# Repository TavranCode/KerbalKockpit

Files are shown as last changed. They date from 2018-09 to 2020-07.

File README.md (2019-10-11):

# KerbalKockpit
A custom control panel for Kerbal Space Program. Heavily cribbed from PeteWasEre

This repository is a place for me to keep and share my code, designs and data for my custom KSP Control Panel.

The contents are:

1. Arduino Code - The modules that run on the Arduino Duemilanove
2. Documentation - Doesn't exist yet!
3. Enclosure Design - The printed graphics used on the panels. Designed to print to a Glowforge
4. PCB design - what it says on the tin.
5. Python Code - The python module that runs at the PC end of the link

If it helps you then please use it. Better yet, consult the original.

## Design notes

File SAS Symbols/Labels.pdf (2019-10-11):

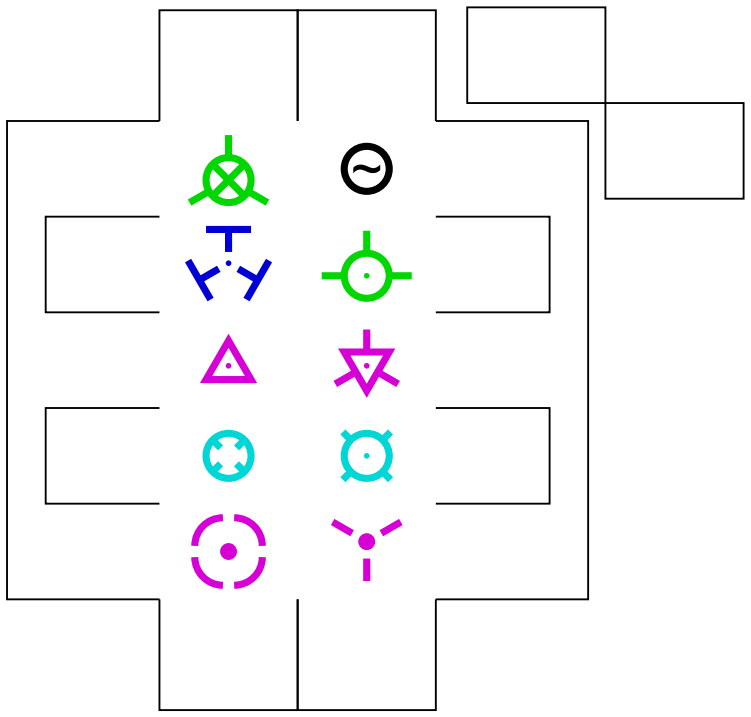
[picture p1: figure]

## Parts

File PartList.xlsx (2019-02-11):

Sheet: Sheet1
Row Labels | Count of Panel
2 axis joystick | 1
3 axis joystick | 1
3axis joystick w/button | 1
cover toggle | 2
large button | 3
led | 16
led button | 10
linpot | 1
momentary | 16
rocker | 3
rotary | 5
toggle | 5
(blank) | 1
Grand Total | 65

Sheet: Control List
Panel | in/out | Function | switch type | plotted | component | Digital Pins | PWM Pins | Analog Pins | Muxed? | Purchased? |  | In sketch | In panel svg
Attitude Control | in | SAS shutoff | large button | X | 1 | 1 | 0 | 0 | 0 | X |  | X
Attitude Control | in | SAS stability | led button | X | 1 | 1 | 0 | 0 | 0 | X |  | X
Attitude Control | in | SAS maneuver | led button | X | 1 | 1 | 0 | 0 | 0 | X |  | X
Attitude Control | in | SAS prograde | led button | X | 1 | 1 | 0 | 0 | 0 | X |  | X
Attitude Control | in | SAS retrograde | led button | X | 1 | 1 | 0 | 0 | 0 | X |  | X
Attitude Control | in | SAS normal | led button | X | 1 | 1 | 0 | 0 | 0 | X |  | X
Attitude Control | in | SAS anti-normal | led button | X | 1 | 1 | 0 | 0 | 0 | X |  | X
Attitude Control | in | SAS radial | led button | X | 1 | 1 | 0 | 0 | 0 | X |  | X
Attitude Control | in | SAS antiradial | led button | X | 1 | 1 | 0 | 0 | 0 | X |  | X
Attitude Control | in | SAS target | led button | X | 1 | 1 | 0 | 0 | 0 | X |  | X
Attitude Control | in | SAS anti-target | led button | X | 1 | 1 | 0 | 0 | 0 | X |  | X
Attitude Control | in | Attitude Joystick | 3axis joystick w/button | X | 2 | 1 | 0 | 3 | 0 | X |  | X
Attitude Control | out | SAS stability lamp | led | X |  | 1 | 0 | 0 | 1 | X |  | X
Attitude Control | out | SAS maneuver lamp | led | X |  | 1 | 0 | 0 | 1 | X |  | X
Attitude Control | out | SAS prograde lamp | led | X |  | 1 | 0 | 0 | 1 | X |  | X
Attitude Control | out | SAS retrograde lamp | led | X |  | 1 | 0 | 0 | 1 | X |  | X
Attitude Control | out | SAS normal lamp | led | X |  | 1 | 0 | 0 | 1 | X |  | X
Attitude Control | out | SAS anti-normal lamp | led | X |  | 1 | 0 | 0 | 1 | X |  | X
Attitude Control | out | SAS radial lamp | led | X |  | 1 | 0 | 0 | 1 | X |  | X
Attitude Control | out | SAS antiradial lamp | led | X |  | 1 | 0 | 0 | 1 | X |  | X
Attitude Control | out | SAS target | led | X |  | 1 | 0 | 0 | 1 | X |  | X
Attitude Control | out | SAS anti-target | led | X |  | 1 | 0 | 0 | 1 | X |  | X
 |  | SAS override |  |  |  |  |  |  |  |  | 19mm red push switch | X
System Control | in | Power |  |  |  | 0 | 0 | 0 | 0 |  |  | X
System Control | in | Reset | key switch |  |  | 0 | 0 | 0 | 0 | X |  | X
System Control | out | Overflow | led | X |  | 1 | 0 | 0 | 1 |  | color change led | X
System Control | out | Power lamp | led | X |  | 1 | 0 | 0 | 1 |  | color change led | X
System Control | out | Error lamp | led | X |  | 1 | 0 | 0 | 1 |  | " | X
Game Control | in | timewarp | rocker | X |  | 2 |  |  |  |  |  | X
Game Control |  | physwarp | rocker | X |  | 2 |  |  |  |  |  | X
Game Control |  | timeoveride | toggle | X |  | 1 |  |  |  |  | 19mm yellow button | X
Game Control |  | quicksave | momentary | X |  | 1 |  |  |  |  | 16mm black button | X
Game Control |  | quickload | momentary | X |  | 1 |  |  |  |  | 16mm black button | X
Game Control |  | vessel switch | rocker | X |  | 2 |  |  |  |  |  | X
Game Control |  | map | momentary | X |  | 1 |  |  |  |  | 16mm black button | X
Game Control |  | reset view | momentary | X |  | 1 |  |  |  |  | 16mm black button | X
Game Control |  | map target toggle | rocker | X |  | 2 |  |  |  |  |  | X
System Control |  | light test |  |  |  | 0 | 0 | 0 | 0 |  |  | X
Action Groups |  | AG 1 | momentary | X |  | 1 |  |  |  |  | tactile switch | X
Action Groups |  | AG 2 | momentary | X |  | 1 |  |  |  |  | tactile switch | X
Action Groups |  | AG 3 | momentary | X |  | 1 |  |  |  |  | tactile switch | X
Action Groups |  | AG 4 | momentary | X |  | 1 |  |  |  |  | tactile switch | X
Action Groups |  | AG 5 | momentary | X |  | 1 |  |  |  |  | tactile switch | X
Action Groups |  | AG 6 | momentary | X |  | 1 |  |  |  |  | tactile switch | X
Action Groups |  | AG 7 | momentary | X |  | 1 |  |  |  |  | tactile switch | X
Action Groups |  | AG 8 | momentary | X |  | 1 |  |  |  |  | tactile switch | X
Action Groups |  | AG 9 | momentary | X |  | 1 |  |  |  |  | tactile switch | X
Action Groups |  | AG 10 | momentary | X |  | 1 |  |  |  |  | tactile switch | X
System Control |  | surface/orbit/target | rotary | X |  | 2 |  |  |  |  |  | X
System Control |  | Lights | toggle | X |  | 1 |  |  |  | toggle |  | X
System Control |  | Gear | toggle | X |  | 1 |  |  |  | toggle |  | X
System Control |  | Brake | toggle | X |  | 1 |  |  |  | toggle |  | X
System Control |  | Light indicator | led | X |  | 1 |  |  |  |  | 3mm led | X
System Control |  | Gear Indicator | led | X |  | 1 |  |  |  |  | 3mm led | X
System Control |  | Brake Indicator | led | X |  | 1 |  |  |  |  | 3mm led | X
Staging |  | Arm Stage | cover toggle |  |  |  |  |  | X | Shield Switch
Staging |  | Stage | large button | X |  | 1 |  |  |  | mushroom Switch | 22 mm green button
Staging |  | Arm Abort | cover toggle |  |  |  |  |  | X | Shield Switch
Staging |  | Abort | large button | X |  | 1 |  |  |  | Mushroom Switch | 22 mm red button
Translation Control |  | 3 axis joystick | 3 axis joystick | X |  |  |  | 3
Translation Control |  | RCS toggle | toggle | X |  | 1
Throttle Control |  | linpot | linpot |  |  |  |  | 1 |  | X
Throttle Control |  | scale switch | rotary |  |  | 0 |  | 0
camera control |  | mode | rotary | X |  | 5
camera control |  | joystick | 2 axis joystick | X
camera control |  | camera zoom | rocker | X |  | 2
output panel:
 |  | fuel level
 |  | elect level
 |  | misc level
 |  | fuel rate
 |  | elect rate
 |  | fuel rate
 |  | stage toggle
 |  | alt. meter
 |  | radio meter
 |  | vel
 |  | vert vel
 |  | hor vel

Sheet: Proto Parts List
Switches: |  |  | Price Per lot | Needed | Min Lot | Price | Measured diameter | Datasheet diameter | Other diameter/notes
1 | Illuminated rectangle button | https://www.ebay.com/itm/10x-DC-12V-Push-Button-Momentary-Self-Reset-Square-Switch-with-LED-Lighted-White-/382028963367 | $10.27 | 10 | 10 | $10.27 | 15.5 | 16
2 | mom-off-mom switch | https://www.aliexpress.com/item/12V-6-Pin-DPDT-Power-Window-Momentary-Rocker-Switch-AC-250V-10A-125V-15A-Switch/32707229587.html | $1.15 | 3 | 1 | $3.45 |  | 21x28.5
4 | 3 axis joystick | https://www.ebay.com/itm/4-Axis-Plastic-Joystick-Potentiometer-For-JH-D400X-R4-10K-4D-with-Button-Wire-/202458110615 | 14 | 1 | 1 | $14.00 |  |  | screws are a 32.5mm square. joy cutout is 35mm round
5 | 3mm led holder |  | 1.04 | 6 | 20 | $1.04 | 5.4 | 6
6 | 5mm led holder |  | 1.56 | 1 | 20 | $1.56 | 7.2 | 8
7 | tactile switch |  | 3.99 |  | 20 | $0.00 | 6.4 | 7
8 | 22mm push | https://www.aliexpress.com/item/16-19-22mm-high-head-flat-head-round-head-metal-self-reset-button-switch-screw-pin/32911160248.html | 4 | 2 | 1 | $8.00 | 21.5 | 22
 | 19mm pushbutton | https://www.aliexpress.com/item/16-19-22mm-high-head-flat-head-round-head-metal-self-reset-button-switch-screw-pin/32911160248.html | 2.64 | 2 | 1 | $5.28 |  | 19
 | 16mm pushbutton | https://www.aliexpress.com/item/16-19-22mm-high-head-flat-head-round-head-metal-self-reset-button-switch-screw-pin/32911160248.html | 1.73 | 4 | 1 | $6.92 |  | 16
9 | rotary pot |  | 0.94 | 2 | 5 | $0.94 | 6.4 | 7
10 | rotary selector switch |  | 7.05 | 5 | 10 | $7.05 | 8.5 | 9
11 | large linpot | vetco |  | 1 |  | #DIV/0! |  |  | 2 mm holes with 77.3 mm between 71mm slot X 2
12 | resource light array | vetco |  | 2 |  | #DIV/0! | 46X6.4
 | DPDT switch | vetco |  |  |  | #DIV/0!
 | SPST switch | vetco |  |  |  | #DIV/0!
 | SPDT switch | vetco |  |  |  | #DIV/0!
 | Slide joystick | https://www.aliexpress.com/item/Hight-quality-Replacement-Parts-Black-3D-Button-Analog-Joystick-for-Sony-for-PSP1000-PSP-1000-PSP/32821042445.html | 2.02 | 1 | 1 | $2.02 |  | NA
 | Key switch |  | 3.5 | 1 | 1 | $3.50 |  | 22
 | 2 axis joystick | https://www.aliexpress.com/item/Free-Ship-2pcs-Model-airplane-B10K-RC-Plane-with-confirm-button-joystick-rocker-3D-RC-helicopter/32672519305.html | 7.35 | 2 | 2 | $7.35 | 22
 | Shielded lit toggle | https://www.sparkfun.com/products/11310 | 2.95 | 2 | 1 | $5.90 |  | 12
 | Small linpot | https://www.sparkfun.com/products/11621 | 3.45 | 1 | 1 |  |  | NA
Other: |  |  |  |  |  | #DIV/0!
 | Heat Shrink |  | 2.49 |  |  | #DIV/0!
 | Standoffs |  | 4.25 |  |  | #DIV/0!
 | Hinges |  |  |  |  | #DIV/0!
 | Headers |  | 0.89 |  |  | #DIV/0!
 | Trim Pots |  | 0.75 | 4 | 20 | $0.75
 | Diodes |  | 0.7 |  | 100 | $0.00
 | ULN arrays |  | 0.94 |  | 10 | $0.00
 | Loose TRansistors |  | 1.06 |  | 20 | $0.00
 | LED strips |  | 2.19 |  |  | #DIV/0!
 | MCP chip |  | 1.21 | 8 |  | #DIV/0!
 | pot handle |  | 1.27 |  | 10 | $0.00
 | Stripboard | https://www.aliexpress.com/item/5-Pcs-6-5x14-5cm-Stripboard-Veroboard-Prototype-Printed-Circuit-Uncut-PCB-Platine-Single-Side-Circuit/32851727414.html | 2.58 |  | 5 | $0.00
 | 74HC4051 |  | 3.04 | 2 | 5 | $3.04
Tools/Other
 | Multimeter
 | Wire Stripper
 | Power Source

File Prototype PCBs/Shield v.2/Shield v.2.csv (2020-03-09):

Source: | C:\Users\Matt Peverill\Dropbox\KerbalKockpit\Prototype PCBs\Shield v.2\Shield v.2.sch
Date: | 2/13/2020 9:13
Tool: | Eeschema (5.1.5)-3
Component Count: | 175
Ref | Value | Footprint | Datasheet | Manufacturer | Vendor
A1 | Conn_01x15 | Connector_PinHeader_2.54mm:PinHeader_1x15_P2.54mm_Vertical | ~ |  | OWN
C1 | C | Capacitor_SMD:C_0603_1608Metric | ~ |  | Mouser
C2 | C | Capacitor_SMD:C_0603_1608Metric | ~ |  | Mouser
C3 | C | Capacitor_SMD:C_0603_1608Metric | ~ |  | Mouser
C4 | C | Capacitor_SMD:C_0603_1608Metric | ~ |  | Mouser
C5 | C | Capacitor_SMD:C_0603_1608Metric | ~ |  | Mouser
D1 | D | Diode_SMD:D_SOD-323 | ~
D2 | D | Diode_SMD:D_SOD-323 | ~
D3 | D | Diode_SMD:D_SOD-323 | ~
D4 | D | Diode_SMD:D_SOD-323 | ~
D5 | D | Diode_SMD:D_SOD-323 | ~
D6 | D | Diode_SMD:D_SOD-323 | ~
D7 | D | Diode_SMD:D_SOD-323 | ~
D8 | D | Diode_SMD:D_SOD-323 | ~
D9 | D | Diode_SMD:D_SOD-323 | ~
D10 | D | Diode_SMD:D_SOD-323 | ~
D11 | D | Diode_SMD:D_SOD-323 | ~
D12 | D | Diode_SMD:D_SOD-323 | ~
D13 | D | Diode_SMD:D_SOD-323 | ~
D14 | D | Diode_SMD:D_SOD-323 | ~
D15 | D | Diode_SMD:D_SOD-323 | ~
D16 | D | Diode_SMD:D_SOD-323 | ~
D17 | 1N4148 | Diode_SMD:D_SOD-323
D18 | 1N4148 | Diode_SMD:D_SOD-323
D19 | 1N4148 | Diode_SMD:D_SOD-323
D20 | 1N4148 | Diode_SMD:D_SOD-323
D21 | 1N4148 | Diode_SMD:D_SOD-323
D22 | 1N4148 | Diode_SMD:D_SOD-323
D23 | 1N4148 | Diode_SMD:D_SOD-323
D24 | 1N4148 | Diode_SMD:D_SOD-323
D25 | 1N4148 | Diode_SMD:D_SOD-323
D26 | 1N4148 | Diode_SMD:D_SOD-323
D27 | 1N4148 | Diode_SMD:D_SOD-323
D28 | 1N4148 | Diode_SMD:D_SOD-323
D29 | 1N4148 | Diode_SMD:D_SOD-323
D30 | 1N4148 | Diode_SMD:D_SOD-323
D31 | 1N4148 | Diode_SMD:D_SOD-323
D32 | 1N4148 | Diode_SMD:D_SOD-323
D33 | 1N4148 | Diode_SMD:D_SOD-323
D34 | 1N4148 | Diode_SMD:D_SOD-323
D35 | 1N4148 | Diode_SMD:D_SOD-323
D36 | 1N4148 | Diode_SMD:D_SOD-323
D37 | 1N4148 | Diode_SMD:D_SOD-323
D38 | 1N4148 | Diode_SMD:D_SOD-323
D39 | 1N4148 | Diode_SMD:D_SOD-323
D40 | 1N4148 | Diode_SMD:D_SOD-323
D41 | 1N4148 | Diode_SMD:D_SOD-323
D42 | 1N4148 | Diode_SMD:D_SOD-323
D43 | 1N4148 | Diode_SMD:D_SOD-323
D44 | 1N4148 | Diode_SMD:D_SOD-323
D45 | 1N4148 | Diode_SMD:D_SOD-323
D46 | 1N4148 | Diode_SMD:D_SOD-323
D47 | 1N4148 | Diode_SMD:D_SOD-323
D48 | 1N4148 | Diode_SMD:D_SOD-323
D49 | 1N4148 | Diode_SMD:D_SOD-323
D50 | 1N4148 | Diode_SMD:D_SOD-323
D51 | 1N4148 | Diode_SMD:D_SOD-323
D52 | 1N4148 | Diode_SMD:D_SOD-323
D53 | 1N4148 | Diode_SMD:D_SOD-323
D54 | 1N4148 | Diode_SMD:D_SOD-323
D55 | 1N4148 | Diode_SMD:D_SOD-323
D56 | 1N4148 | Diode_SMD:D_SOD-323
D57 | 1N4148 | Diode_SMD:D_SOD-323
D58 | 1N4148 | Diode_SMD:D_SOD-323
D59 | 1N4148 | Diode_SMD:D_SOD-323
D60 | 1N4148 | Diode_SMD:D_SOD-323
D61 | 1N4148 | Diode_SMD:D_SOD-323
D62 | 1N4148 | Diode_SMD:D_SOD-323
D63 | 1N4148 | Diode_SMD:D_SOD-323
D64 | 1N4148 | Diode_SMD:D_SOD-323
D65 | 1N4148 | Diode_SMD:D_SOD-323
D66 | 1N4148 | Diode_SMD:D_SOD-323
D67 | 1N4148 | Diode_SMD:D_SOD-323
D68 | 1N4148 | Diode_SMD:D_SOD-323
D69 | 1N4148 | Diode_SMD:D_SOD-323
D70 | 1N4148 | Diode_SMD:D_SOD-323
D71 | 1N4148 | Diode_SMD:D_SOD-323
D72 | 1N4148 | Diode_SMD:D_SOD-323
D73 | 1N4148 | Diode_SMD:D_SOD-323
D74 | 1N4148 | Diode_SMD:D_SOD-323
D75 | 1N4148 | Diode_SMD:D_SOD-323
D76 | 1N4148 | Diode_SMD:D_SOD-323
D77 | 1N4148 | Diode_SMD:D_SOD-323
D78 | 1N4148 | Diode_SMD:D_SOD-323
D79 | 1N4148 | Diode_SMD:D_SOD-323
D80 | 1N4148 | Diode_SMD:D_SOD-323
G1 | Conn_01x15 | Connector_PinHeader_2.54mm:PinHeader_1x15_P2.54mm_Vertical | ~ |  | Own
J1 | Conn_01x04 | Connector_PinHeader_2.54mm:PinHeader_1x04_P2.54mm_Vertical | ~ |  | Own
J2 | Conn_01x06 | Connector_PinHeader_2.54mm:PinHeader_1x06_P2.54mm_Vertical | ~ |  | Own
J3 | Conn_01x04 | Connector_PinHeader_2.54mm:PinHeader_1x04_P2.54mm_Vertical | ~ |  | Own
J4 | Conn_01x05 | Connector_PinHeader_2.54mm:PinHeader_1x05_P2.54mm_Vertical | ~ |  | Own
J5 | Motor | Connector_PinHeader_2.54mm:PinHeader_1x05_P2.54mm_Vertical | ~ |  | Own
J6 | Conn_01x03 | Connector_PinHeader_2.54mm:PinHeader_1x03_P2.54mm_Vertical | ~ |  | Own
J7 | Conn_01x07 | Connector_PinHeader_2.54mm:PinHeader_1x07_P2.54mm_Vertical | ~ |  | Own
J8 | Conn_01x04 | Connector_PinHeader_2.54mm:PinHeader_1x04_P2.54mm_Vertical | ~ |  | Own
J9 | Conn_Reset | Connector_PinHeader_2.54mm:PinHeader_1x02_P2.54mm_Vertical | ~ |  | Own
J10 | i2cA | Connector_PinHeader_2.54mm:PinHeader_2x04_P2.54mm_Vertical | ~ |  | Own
J11 | i2cB | Connector_PinHeader_2.54mm:PinHeader_2x04_P2.54mm_Vertical | ~ |  | Own
J14 | Conn_SysBut | Connector_PinHeader_2.54mm:PinHeader_1x04_P2.54mm_Vertical | ~ |  | Own
J15 | Conn_bLight | Connector_PinHeader_2.54mm:PinHeader_1x02_P2.54mm_Vertical | ~ |  | Own
J16 | Conn_SysLED | Connector_PinHeader_2.54mm:PinHeader_2x02_P2.54mm_Vertical | ~ |  | Own
J17 | LEDs_A | Connector_PinHeader_2.54mm:PinHeader_2x08_P2.54mm_Vertical | ~ |  | Own
J18 | LEDs_B | Connector_PinHeader_2.54mm:PinHeader_2x08_P2.54mm_Vertical | ~ |  | Own
J19B1 | Jumper_NO_Small | Connector_PinHeader_2.54mm:PinHeader_1x02_P2.54mm_Vertical | ~ |  | Own
J19C1 | Jumper_NO_Small | Connector_PinHeader_2.54mm:PinHeader_1x02_P2.54mm_Vertical | ~ |  | Own
J19C2 | Jumper_NO_Small | Connector_PinHeader_2.54mm:PinHeader_1x02_P2.54mm_Vertical | ~ |  | Own
J19D1 | Jumper_NO_Small | Connector_PinHeader_2.54mm:PinHeader_1x02_P2.54mm_Vertical | ~ |  | Own
J19F1 | Jumper_NO_Small | Connector_PinHeader_2.54mm:PinHeader_1x02_P2.54mm_Vertical | ~ |  | Own
J19F2 | Jumper_NO_Small | Connector_PinHeader_2.54mm:PinHeader_1x02_P2.54mm_Vertical | ~ |  | Own
J19G1 | Jumper_NO_Small | Connector_PinHeader_2.54mm:PinHeader_1x02_P2.54mm_Vertical | ~ |  | Own
J19H1 | Jumper_NO_Small | Connector_PinHeader_2.54mm:PinHeader_1x02_P2.54mm_Vertical | ~ |  | Own
J20 | JumpSwitch | Connector_PinHeader_2.54mm:PinHeader_2x08_P2.54mm_Vertical |  |  | Own
J21 | JumpSwitch | Connector_PinHeader_2.54mm:PinHeader_2x08_P2.54mm_Vertical |  |  | Own
J22 | JumpSwitch | Connector_PinHeader_2.54mm:PinHeader_2x08_P2.54mm_Vertical |  |  | Own
J23 | JumpSwitch | Connector_PinHeader_2.54mm:PinHeader_2x08_P2.54mm_Vertical |  |  | Own
J24 | JumpSwitch | Connector_PinHeader_2.54mm:PinHeader_2x08_P2.54mm_Vertical |  |  | Own
J25 | JumpSwitch | Connector_PinHeader_2.54mm:PinHeader_2x08_P2.54mm_Vertical |  |  | Own
J26A1 | Jumper_NO_Small | Connector_PinHeader_2.54mm:PinHeader_1x02_P2.54mm_Vertical | ~ |  | Own
J26B1 | Jumper_NO_Small | Connector_PinHeader_2.54mm:PinHeader_1x02_P2.54mm_Vertical | ~ |  | Own
J26C1 | Jumper_NO_Small | Connector_PinHeader_2.54mm:PinHeader_1x02_P2.54mm_Vertical | ~ |  | Own
J26D1 | Jumper_NO_Small | Connector_PinHeader_2.54mm:PinHeader_1x02_P2.54mm_Vertical | ~ |  | Own
J26E1 | Jumper_NO_Small | Connector_PinHeader_2.54mm:PinHeader_1x02_P2.54mm_Vertical | ~ |  | Own
J26F1 | Jumper_NO_Small | Connector_PinHeader_2.54mm:PinHeader_1x02_P2.54mm_Vertical | ~ |  | Own
J26G1 | Jumper_NO_Small | Connector_PinHeader_2.54mm:PinHeader_1x02_P2.54mm_Vertical | ~ |  | Own
J26H1 | Jumper_NO_Small | Connector_PinHeader_2.54mm:PinHeader_1x02_P2.54mm_Vertical | ~ |  | Own
Q1 | Q_NMOS_DIM | Package_TO_SOT_SMD:SOT-23 | ~ |  | Mouser
Q2 | Q_NMOS_DIM | Package_TO_SOT_SMD:SOT-23 | ~ |  | Mouser
R1 | R4.7k | Resistor_SMD:R_0603_1608Metric | ~ |  | Mouser
R2 | R4.7k | Resistor_SMD:R_0603_1608Metric | ~ |  | Mouser
R3 | R | Resistor_SMD:R_0603_1608Metric | ~ |  | Mouser
R4 | R | Resistor_SMD:R_0603_1608Metric | ~ |  | Mouser
R5 | R | Resistor_SMD:R_0603_1608Metric | ~ |  | Mouser
R6 | R | Resistor_SMD:R_0603_1608Metric | ~ |  | Mouser
R7 | R | Resistor_SMD:R_0603_1608Metric | ~ |  | Mouser
R8 | R | Resistor_SMD:R_0603_1608Metric | ~ |  | Mouser
R9 | R | Resistor_SMD:R_0603_1608Metric | ~ |  | Mouser
R10 | R | Resistor_SMD:R_0603_1608Metric | ~ |  | Mouser
R11 | R | Resistor_SMD:R_0603_1608Metric | ~ |  | Mouser
R12 | R | Resistor_SMD:R_0603_1608Metric | ~ |  | Mouser
R13 | R | Resistor_SMD:R_0603_1608Metric | ~ |  | Mouser
R14 | R | Resistor_SMD:R_0603_1608Metric | ~ |  | Mouser
R15 | R | Resistor_SMD:R_0603_1608Metric | ~ |  | Mouser
R16 | R | Resistor_SMD:R_0603_1608Metric | ~ |  | Mouser
R17 | R | Resistor_SMD:R_0603_1608Metric | ~ |  | Mouser
R18 | R | Resistor_SMD:R_0603_1608Metric | ~ |  | Mouser
R19 | R | Resistor_SMD:R_0603_1608Metric | ~ |  | Mouser
R20 | R | Resistor_SMD:R_0603_1608Metric | ~ |  | Mouser
R21 | R1k | Resistor_SMD:R_0603_1608Metric | ~ |  | Mouser
R22 | R1k | Resistor_SMD:R_0603_1608Metric | ~ |  | Mouser
R23 | R4.7k | Resistor_SMD:R_0603_1608Metric | ~ |  | Mouser
R24 | R4.7k | Resistor_SMD:R_0603_1608Metric | ~ |  | Mouser
R25 | R4.7k | Resistor_SMD:R_0603_1608Metric | ~ |  | Mouser
R26 | R4.7k | Resistor_SMD:R_0603_1608Metric | ~ |  | Mouser
R27 | R4.7k | Resistor_SMD:R_0603_1608Metric | ~ |  | Mouser
R28 | R4.7k | Resistor_SMD:R_0603_1608Metric | ~ |  | Mouser
R29 | R4.7k | Resistor_SMD:R_0603_1608Metric | ~ |  | Mouser
R30 | R4.7k | Resistor_SMD:R_0603_1608Metric | ~ |  | Mouser
R31 | R4.7k | Resistor_SMD:R_0603_1608Metric | ~ |  | Mouser
R32 | R4.7k | Resistor_SMD:R_0603_1608Metric | ~ |  | Mouser
SW1 | SW_Push | Kicad Parts:SW_PUSH-12mm_widepinholes |  |  |  | https://www.aliexpress.com/item/1649844130.html?spm=a2g0s.9042311.0.0.27424c4daOGlAI
SW2 | SW_Push | Kicad Parts:SW_PUSH-12mm_widepinholes
SW3 | SW_Push | Kicad Parts:SW_PUSH-12mm_widepinholes
SW4 | SW_Push | Kicad Parts:SW_PUSH-12mm_widepinholes
SW5 | SW_Push | Kicad Parts:SW_PUSH-12mm_widepinholes
SW6 | SW_Push | Kicad Parts:SW_PUSH-12mm_widepinholes
SW7 | SW_Push | Kicad Parts:SW_PUSH-12mm_widepinholes
SW8 | SW_Push | Kicad Parts:SW_PUSH-12mm_widepinholes
SW9 | SW_Push | Kicad Parts:SW_PUSH-12mm_widepinholes
SW10 | SW_Push | Kicad Parts:SW_PUSH-12mm_widepinholes
U1 | 74HC4051 | Package_SO:SSOP-16_3.9x4.9mm_P0.635mm | http://www.ti.com/lit/ds/symlink/cd74hc4051.pdf |  | Mouser
U2 | MCP23017_0x20_in | Package_SO:SSOP-28_5.3x10.2mm_P0.65mm | http://ww1.microchip.com/downloads/en/DeviceDoc/20001952C.pdf |  | Mouser
U3 | MCP23017_0x21_out | Package_SO:SSOP-28_5.3x10.2mm_P0.65mm | http://ww1.microchip.com/downloads/en/DeviceDoc/20001952C.pdf |  | Mouser
U4 | ULN2803A | Package_SO:SOIC-18W_7.5x11.6mm_P1.27mm | http://www.ti.com/lit/ds/symlink/uln2803a.pdf |  | Mouser
U5 | ULN2803A | Package_SO:SOIC-18W_7.5x11.6mm_P1.27mm | http://www.ti.com/lit/ds/symlink/uln2803a.pdf |  | Mouser
V1 | Conn_01x15 | Connector_PinHeader_2.54mm:PinHeader_1x15_P2.54mm_Vertical | ~ |  | OWN
 | MOUNTING HARDWARE | #
Shield - Stand-offs | 5/32" #2 standoff | 4 | https://www.mouser.com/ProductDetail/710-970050244
Shield - Panel Screws |  | 4 | https://www.boltdepot.com/Metric_machine_screws_Phillips_flat_head_Stainless_steel_18-8_(A-2)_2mm_x_0.4mm.aspx
Shield - Board Screws |  | 4 | https://www.boltdepot.com/Product-Details.aspx?product=6844
Shield - Washers |  | 0 | https://www.boltdepot.com/Product-Details.aspx?product=7364
Button Panel - Stand-offs | 5/32" #2 standoff | 3
Button Panel - Stand-offs
Button Panel - Panel Screws
Button Panel - Board Screws
Button Panel - Washers
PSP Analog Screws |  | 4 | https://www.metricscrews.us/index.php?main_page=product_info&products_id=1347&zenid=k8udfabh2ck7jem5e6mimm35a2
Adhesive Cable Clips |  |  | https://www.amazon.com/gp/product/B072XJT436/ref=crt_ewc_img_dp_2?ie=UTF8&psc=1&smid=AWAGKS3NENVQT
Paper Clip |  |  | https://www.amazon.com/gp/product/B001F6TDEW/ref=crt_ewc_title_dp_1?ie=UTF8&psc=1&smid=ATVPDKIKX0DER
#4Screw for Paper Clip |  | 1 w/nut and washer

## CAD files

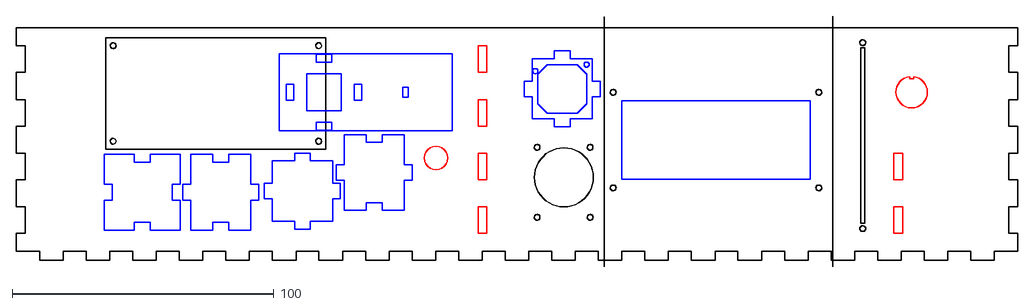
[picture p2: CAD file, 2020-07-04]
Enclosure Design/Cuttest 2-16-2020.dxf
382.2 x 95.7

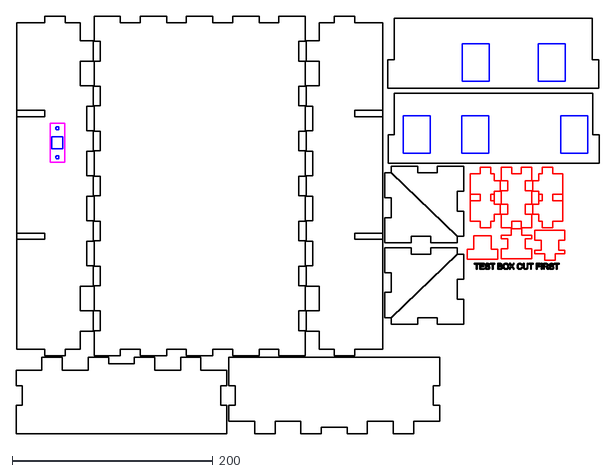
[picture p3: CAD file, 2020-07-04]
Enclosure Design/Panel-v3/Enclosure.dxf
581.1 x 416.2

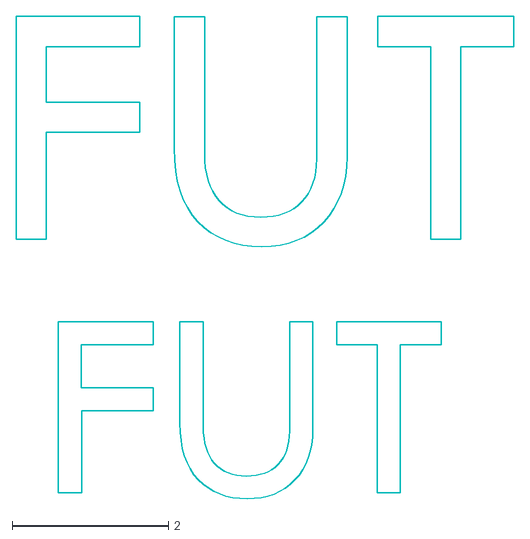
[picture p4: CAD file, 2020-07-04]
Enclosure Design/Panel-v3/Test and Development Files/Text.dxf
6.38 x 6.18

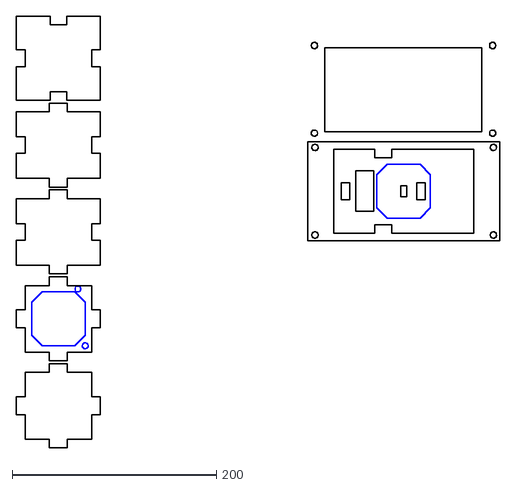
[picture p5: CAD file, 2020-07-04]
Enclosure Design/Cuttest 2-16-2020b.dxf
472.8 x 422.2

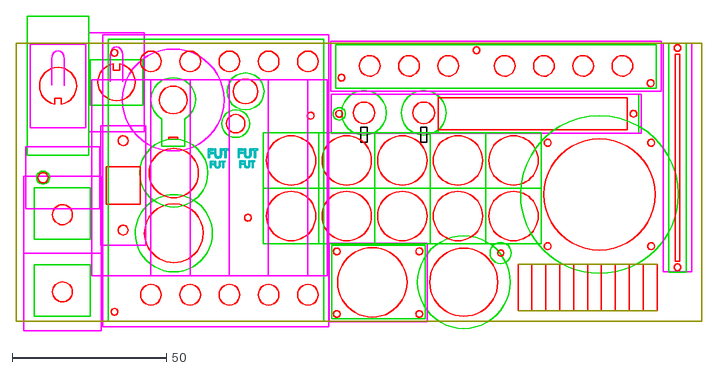
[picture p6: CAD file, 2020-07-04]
Enclosure Design/Panel-v3/Test and Development Files/AcrylicCutTest1.dxf
222.0 x 101.7

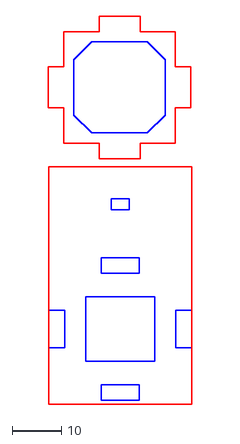
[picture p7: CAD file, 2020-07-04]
Enclosure Design/Panel-v3/Translation Control Parts 2.dxf
29.1 x 78.9

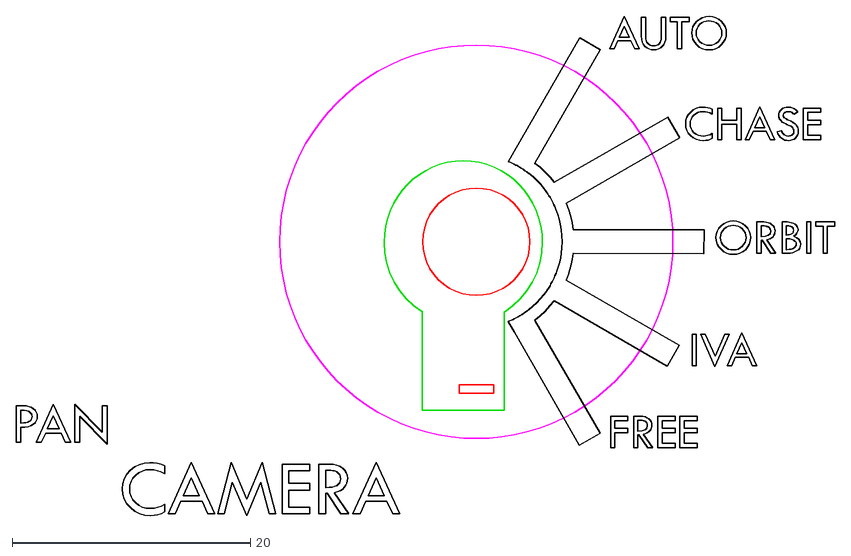
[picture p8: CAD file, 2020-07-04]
Enclosure Design/Panel-v3/Test and Development Files/finalengravetest.dxf
68.7 x 41.9

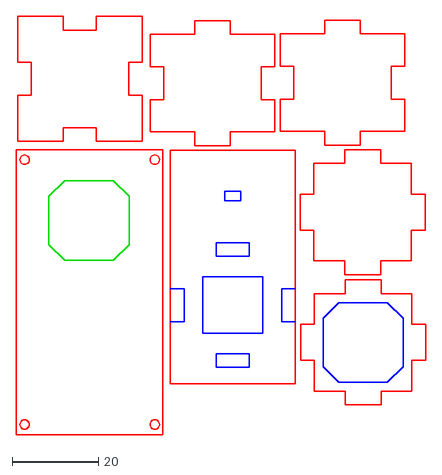
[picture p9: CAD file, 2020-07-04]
Enclosure Design/Panel-v3/Translation Control Parts.dxf
95.1 x 97.2

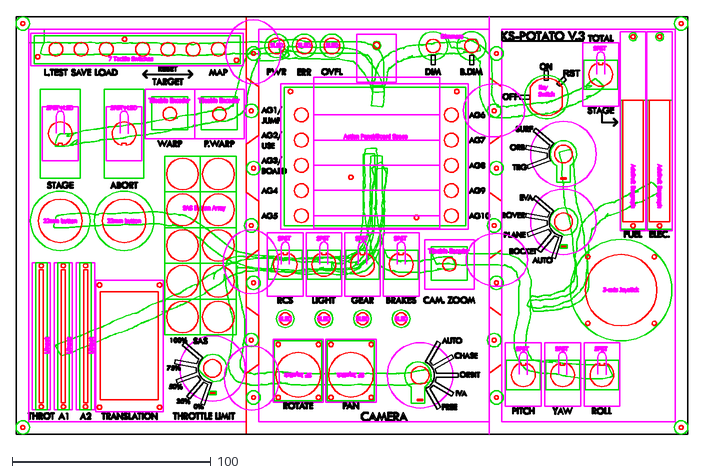
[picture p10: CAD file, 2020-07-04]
Enclosure Design/Panel-v3/Panel-v3.dxf
338.5 x 210.6

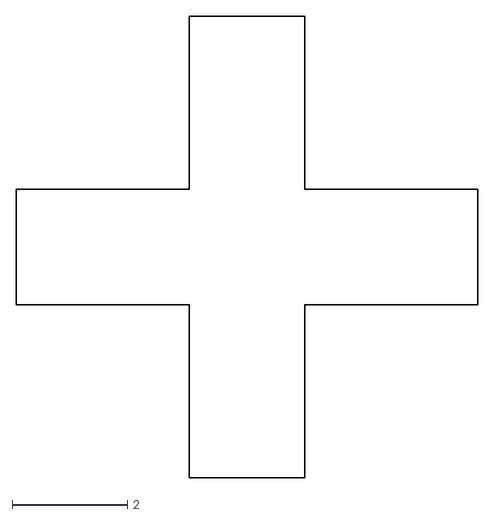
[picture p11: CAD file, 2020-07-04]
Enclosure Design/Panel-v3/Test and Development Files/2mmcross.dxf
8.00 x 8.00

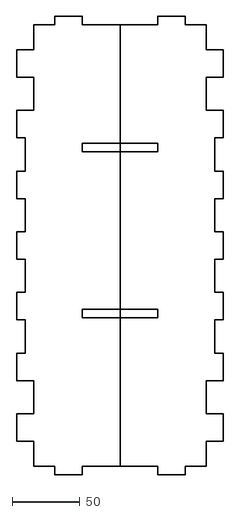
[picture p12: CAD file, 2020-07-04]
Enclosure Design/Panel-v3/NewSides.dxf
152.4 x 338.5

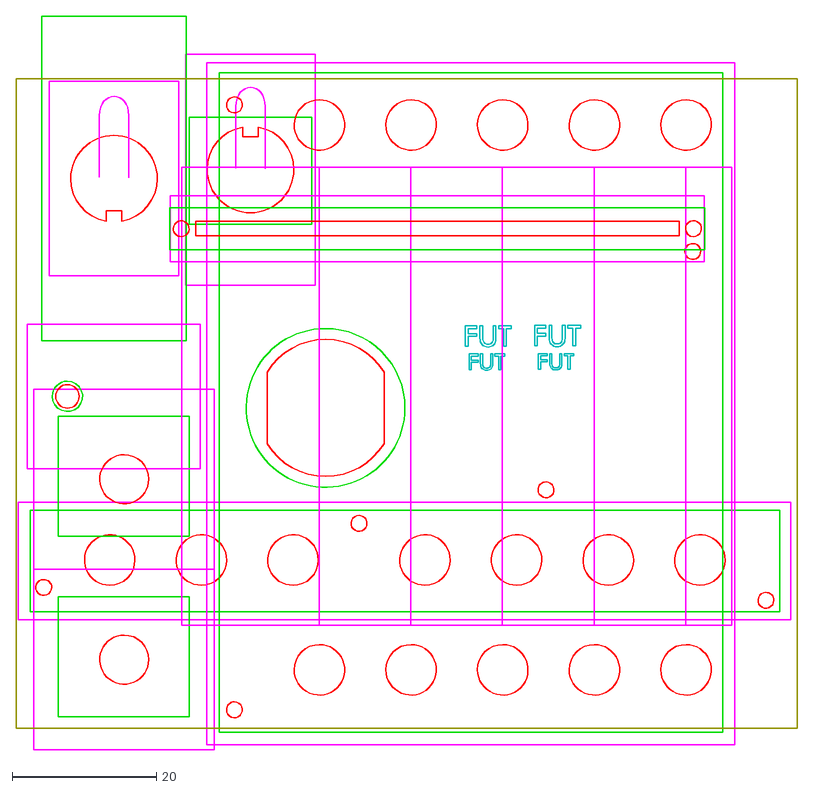
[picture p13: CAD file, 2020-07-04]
Enclosure Design/Panel-v3/Test and Development Files/AcrylicCutTest2.dxf
108.2 x 101.7

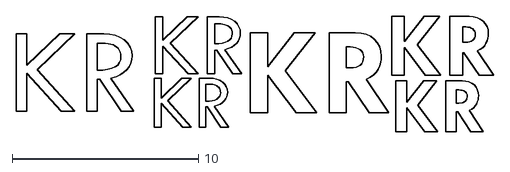
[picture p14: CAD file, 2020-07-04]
Enclosure Design/Panel-v3/Test and Development Files/Futura Sample.dxf
25.6 x 6.18

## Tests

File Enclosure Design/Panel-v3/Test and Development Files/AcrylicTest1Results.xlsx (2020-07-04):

 | Tested | Corrections | Re-design | Test
Rotary | X
Brain Board | X | Increase Button width to 7mm | X | X
Button Board | X | " | X | X
Linpot | X | Slot width > 1.8-2mm | X | X
Ada barplot | X
encoder | X | hole too small - spacing is perfect. Should be 6.5mm | X | X
switch |  | counter-rotation is too long | X | just a little looser
shield switch |  | " | X | "
5mm led
3mm led
usb port | X
22mm button | X
18mm button | X
KeySwitch | X | Add sides and make hole bigger | X
Dimmers | x
Big Joystick
SF Joystick | X
SAS array | X
Rotary Switch | X
Notes Sheet | X

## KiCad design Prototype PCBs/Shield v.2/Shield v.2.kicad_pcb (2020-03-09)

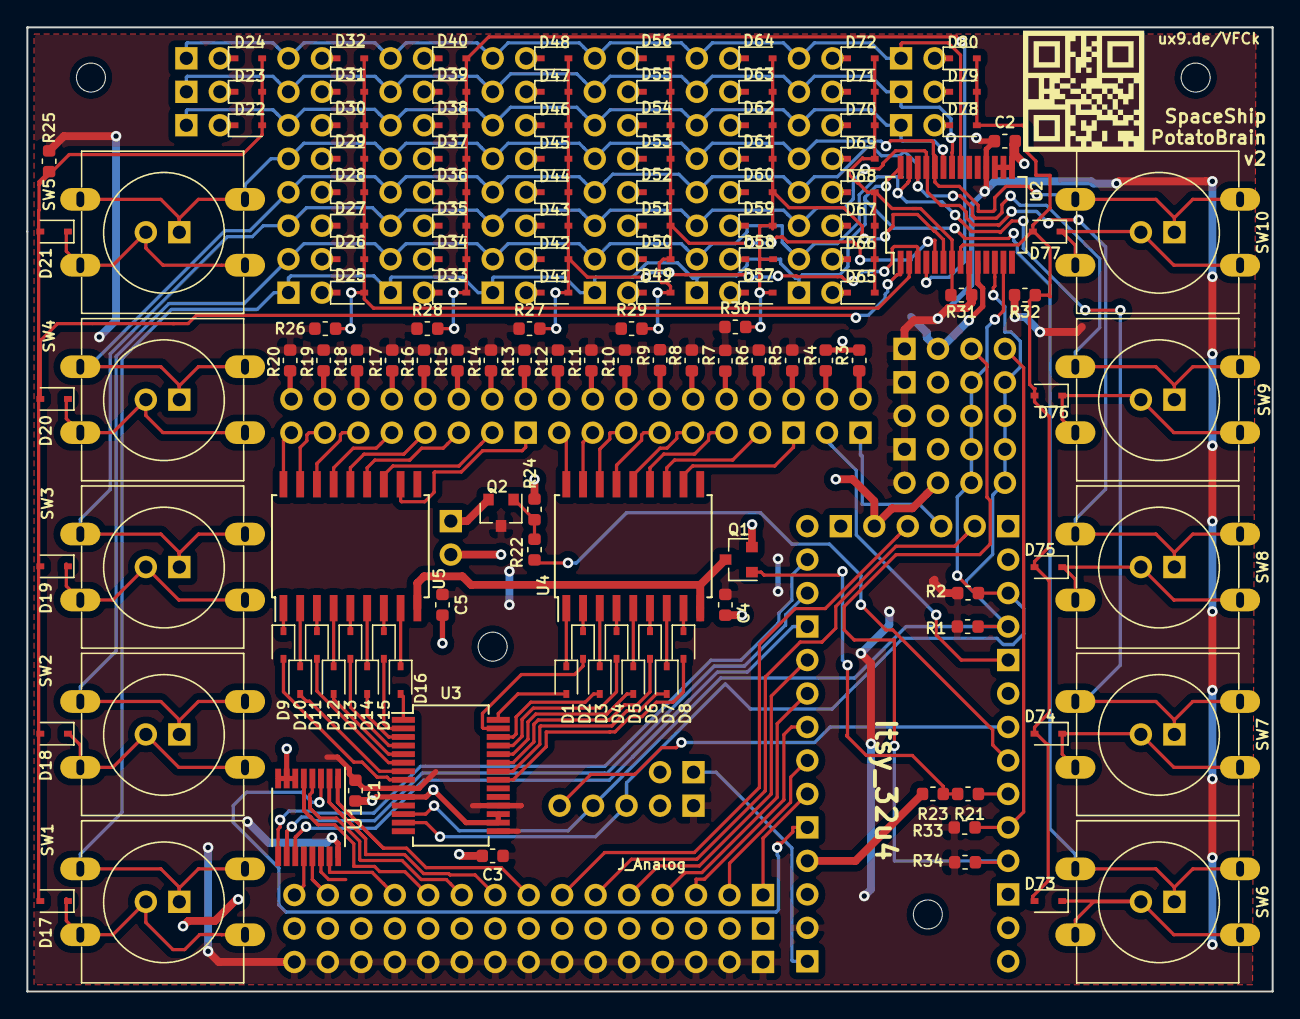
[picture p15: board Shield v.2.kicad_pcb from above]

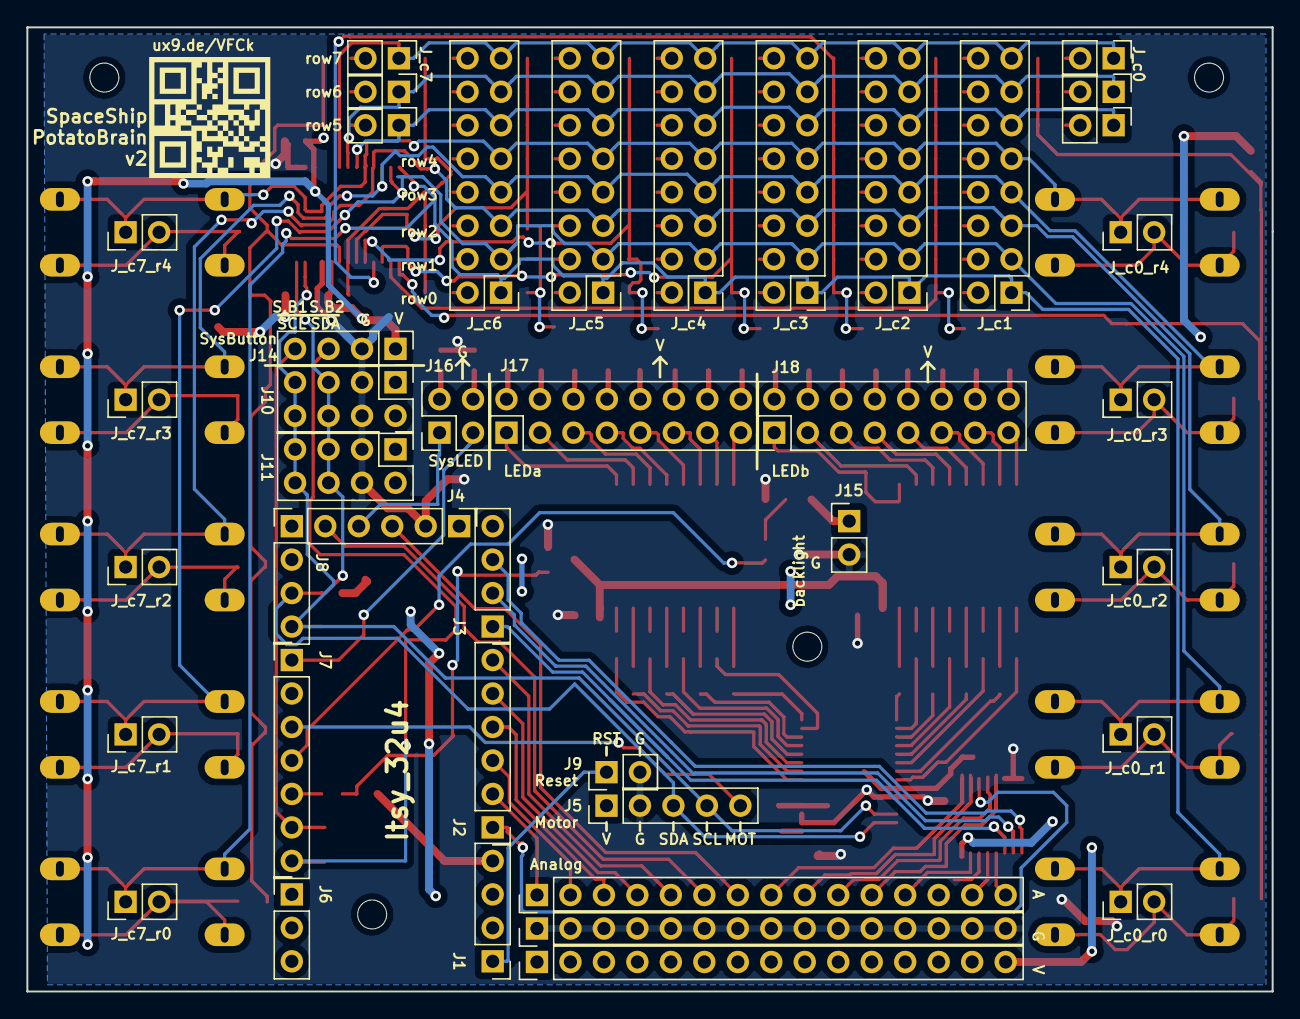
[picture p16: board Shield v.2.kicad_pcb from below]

Board: 2 copper layers, 94.5 x 73.2 mm, 183 parts (42 on the bottom side), 181 nets.

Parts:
A: Conn_01x15; PinHeader_1x15_P2.54mm_Vertical
C1, C2, C3, C4, C5: C; C_0603_1608Metric
D1, D2, D3, D4, D5, D6, D7, D8, D9, D10, D11, D12, D13, D14, D15, D16: D; D_SOD-323
D17, D18, D19, D20, D21, D22, D23, D24, D25, D26, D27, D28, D29, D30, D31, D32, D33, D34, D35, D36, D37, D38, D39, D40, D41, D42, D43, D44, D45, D46, D47, D48, D49, D50, D51, D52, D53, D54, D55, D56, D57, D58, D59, D60, D61, D62, D63, D64, D65, D66, D67, D68, D69, D70, D71, D72, D73, D74, D75, D76, D77, D78, D79, D80: 1N4148; D_SOD-323
G: Conn_01x15; PinHeader_1x15_P2.54mm_Vertical
J1, J3, J8: Conn_01x04; PinHeader_1x04_P2.54mm_Vertical
J2: Conn_01x06; PinHeader_1x06_P2.54mm_Vertical
J4: Conn_01x05; PinHeader_1x05_P2.54mm_Vertical
J5: Motor; PinHeader_1x05_P2.54mm_Vertical
J6: Conn_01x03; PinHeader_1x03_P2.54mm_Vertical
J7: Conn_01x07; PinHeader_1x07_P2.54mm_Vertical
J9: Conn_Reset; PinHeader_1x02_P2.54mm_Vertical
J10: i2cA; PinHeader_2x04_P2.54mm_Vertical
J11: i2cB; PinHeader_2x04_P2.54mm_Vertical
J14: Conn_SysBut; PinHeader_1x04_P2.54mm_Vertical
J15: Conn_bLight; PinHeader_1x02_P2.54mm_Vertical
J16: Conn_SysLED; PinHeader_2x02_P2.54mm_Vertical
J17: LEDs_A; PinHeader_2x08_P2.54mm_Vertical
J18: LEDs_B; PinHeader_2x08_P2.54mm_Vertical
J19F2, J19G1, J26F1, J26G1: Jumper_NO_Small; PinHeader_1x02_P2.54mm_Vertical
J_c0, J_c0_r0, J_c0_r1, J_c0_r2, J_c0_r3, J_c0_r4, J_c7, J_c7_r0, J_c7_r1, J_c7_r2, J_c7_r3, J_c7_r4: Jumper_NO_Small; PinHeader_1x02_P2.54mm_Vertical
J_c1, J_c2, J_c3, J_c4, J_c5, J_c6: JumpSwitch; PinHeader_2x08_P2.54mm_Vertical
Mount1, Mount2, Mount3, Mount4: MountingHole_2.2mm_M2
Q1, Q2: Q_NMOS_DIM; SOT-23
QR*****: ux9.de/VFCk; ux9.de_VFCk
QR*****#2: ux9.de/VFCk; ux9.de_VFCk
R1, R2, R23, R24, R25, R26, R27, R28, R29, R30, R31, R32, R33, R34: R4.7k; R_0603_1608Metric
R3, R4, R5, R6, R7, R8, R9, R10, R11, R12, R13, R14, R15, R16, R17, R18, R19, R20: R; R_0603_1608Metric
R21, R22: R1k; R_0603_1608Metric
SW1, SW2, SW3, SW4, SW5, SW6, SW7, SW8, SW9, SW10: SW_Push; SW_PUSH-12mm_widepinholes
U1: 74HC4051; TSSOP-16_4.4x5mm_P0.65mm
U2: MCP23017_0x20_in; SSOP-28_5.3x10.2mm_P0.65mm
U3: MCP23017_0x21_out; SSOP-28_5.3x10.2mm_P0.65mm
U4, U5: ULN2803A; SOIC-18W_7.5x11.6mm_P1.27mm
V: Conn_01x15; PinHeader_1x15_P2.54mm_Vertical

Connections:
+5V: C1.1, C2.1, C3.1, C4.1, C5.1, J1.2, J5.1, J10.1, J10.2, J11.1, J11.2, J14.1, Q2.3, R1.1, R2.1, R5.1, R6.1, R7.1, R8.1, R9.1, R10.1, R11.1, R12.1, R13.1, R14.1, R15.1, R16.1, R17.1, R18.1, R19.1, R20.1, R25.1, R26.1, R27.1, R28.1, R29.1, R30.1, R31.1, R32.1, R33.1, R34.1, U1.16, U2.9, U2.18, U3.9, U3.15, U3.18, V.1, V.2, V.3, V.4, V.5, V.6, V.7, V.8, V.9, V.10, V.11, V.12, V.13, V.14, V.15
/5*: J7.1, J16.3
/9*: J5.5, J7.3
/10*: J7.4, R22.2
/11*: J7.5, R21.2
/12: J7.6, J14.4, R33.2
/13: J7.7, J14.3, R34.2
/14: J3.3, U1.9
/15: J3.1, U1.11
/16: J3.2, U1.10
/A0: J2.1, U1.3
/A1: A.1, J2.2
/A2: A.2, J2.3
/A3: A.3, J2.4
/A4: A.4, J2.5
/A5: A.5, J2.6
/A6: A.6, J4.5
/A7: J4.4, J16.1
/A8: A.7, J4.3
/DIM: Q1.3, U4.9, U5.9
/Input Matrix/input_c0: D17.2, D18.2, D19.2, D20.2, D21.2, D22.2, D23.2, D24.2, R25.2, U2.1
/Input Matrix/input_c1: D25.2, D26.2, D27.2, D28.2, D29.2, D30.2, D31.2, D32.2, R26.2, U2.2
/Input Matrix/input_c2: D33.2, D34.2, D35.2, D36.2, D37.2, D38.2, D39.2, D40.2, R28.2, U2.4
/Input Matrix/input_c3: D41.2, D42.2, D43.2, D44.2, D45.2, D46.2, D47.2, D48.2, R27.2, U2.3
/Input Matrix/input_c4: D49.2, D50.2, D51.2, D52.2, D53.2, D54.2, D55.2, D56.2, R29.2, U2.5
/Input Matrix/input_c5: D57.2, D58.2, D59.2, D60.2, D61.2, D62.2, D63.2, D64.2, R30.2, U2.6
/Input Matrix/input_c6: D65.2, D66.2, D67.2, D68.2, D69.2, D70.2, D71.2, D72.2, R31.2, U2.7
/Input Matrix/input_c7: D73.2, D74.2, D75.2, D76.2, D77.2, D78.2, D79.2, D80.2, R32.2, U2.8
/Input Matrix/input_r0: J_c0_r0.1, J_c1.1, J_c2.1, J_c3.1, J_c4.1, J_c5.1, J_c6.1, J_c7_r0.1, SW1.1, SW6.1, U2.28
/Input Matrix/input_r1: J_c0_r1.1, J_c1.3, J_c2.3, J_c3.3, J_c4.3, J_c5.3, J_c6.3, J_c7_r1.1, SW2.1, SW7.1, U2.27
/Input Matrix/input_r2: J_c0_r2.1, J_c1.5, J_c2.5, J_c3.5, J_c4.5, J_c5.5, J_c6.5, J_c7_r2.1, SW3.1, SW8.1, U2.25
/Input Matrix/input_r3: J_c0_r3.1, J_c1.7, J_c2.7, J_c3.7, J_c4.7, J_c5.7, J_c6.7, J_c7_r3.1, SW4.1, SW9.1, U2.26
/Input Matrix/input_r4: J_c0_r4.1, J_c1.9, J_c2.9, J_c3.9, J_c4.9, J_c5.9, J_c6.9, J_c7_r4.1, SW5.1, SW10.1, U2.24
/Input Matrix/input_r5: J19F2.1, J26F1.1, J_c1.11, J_c2.11, J_c3.11, J_c4.11, J_c5.11, J_c6.11, U2.23
/Input Matrix/input_r6: J19G1.1, J26G1.1, J_c1.13, J_c2.13, J_c3.13, J_c4.13, J_c5.13, J_c6.13, U2.22
/Input Matrix/input_r7: J_c0.1, J_c1.15, J_c2.15, J_c3.15, J_c4.15, J_c5.15, J_c6.15, J_c7.1, U2.21
/O.A0: D9.1, U5.1
/O.A1: D10.1, U5.2
/O.A2: D11.1, U5.3
/O.A3: D12.1, U5.4
/O.A4: D13.1, U5.5
/O.A5: D14.1, U5.6
/O.A6: D15.1, U5.7
/O.A7: D16.1, U5.8
/O.B0: D1.1, U4.1
/O.B1: D2.1, U4.2
/O.B2: D3.1, U4.3
/O.B3: D4.1, U4.4
/O.B4: D5.1, U4.5
/O.B5: D6.1, U4.6
/O.B6: D7.1, U4.7
/O.B7: D8.1, U4.8
/RST: J1.1, J9.1
/SCL: J5.4, J8.4, J10.7, J10.8, J11.7, J11.8, R1.2, U2.12, U3.12
/SDA: J5.3, J8.3, J10.5, J10.6, J11.5, J11.6, R2.2, U2.13, U3.13
/uA0: A.14, U1.13
/uA1: A.13, U1.14
/uA2: A.12, U1.15
/uA3: A.15, U1.12
/uA4: A.8, U1.1
/uA5: A.11, U1.5
/uA6: A.9, U1.2
/uA7: A.10, U1.4
GND: C1.2, C2.2, C3.2, C4.2, C5.2, G.1, G.2, G.3, G.4, G.5, G.6, G.7, G.8, G.9, G.10, G.11, G.12, G.13, G.14, G.15, J1.4, J4.2, J5.2, J9.2, J10.3, J10.4, J11.3, J11.4, J14.2, J15.2, Q1.2, R3.1, R4.1, R23.1, R24.1, U1.6, U1.7, U1.8, U2.10, U2.15, U2.16, U2.17, U3.10, U3.16, U3.17
unnamed: D1.2, U3.28
unnamed: D2.2, U3.27
unnamed: D3.2, U3.26
unnamed: D4.2, U3.25
unnamed: D5.2, U3.24
unnamed: D6.2, U3.23
unnamed: D7.2, U3.22
unnamed: D8.2, U3.21
unnamed: D9.2, U3.8
unnamed: D10.2, U3.7
unnamed: D11.2, U3.6
unnamed: D12.2, U3.5
unnamed: D13.2, U3.4
unnamed: D14.2, U3.3
unnamed: D15.2, U3.2
unnamed: D16.2, U3.1
unnamed: D17.1, J_c0_r0.2, SW1.2
unnamed: D18.1, J_c0_r1.2, SW2.2
unnamed: D19.1, J_c0_r2.2, SW3.2
unnamed: D20.1, J_c0_r3.2, SW4.2
unnamed: D21.1, J_c0_r4.2, SW5.2
unnamed: D22.1, J19F2.2
unnamed: D23.1, J19G1.2
unnamed: D24.1, J_c0.2
unnamed: D25.1, J_c1.2
unnamed: D26.1, J_c1.4
unnamed: D27.1, J_c1.6
unnamed: D28.1, J_c1.8
unnamed: D29.1, J_c1.10
unnamed: D30.1, J_c1.12
unnamed: D31.1, J_c1.14
unnamed: D32.1, J_c1.16
unnamed: D33.1, J_c2.2
unnamed: D34.1, J_c2.4
unnamed: D35.1, J_c2.6
unnamed: D36.1, J_c2.8
unnamed: D37.1, J_c2.10
unnamed: D38.1, J_c2.12
unnamed: D39.1, J_c2.14
unnamed: D40.1, J_c2.16
unnamed: D41.1, J_c3.2
unnamed: D42.1, J_c3.4
unnamed: D43.1, J_c3.6
unnamed: D44.1, J_c3.8
unnamed: D45.1, J_c3.10
unnamed: D46.1, J_c3.12
unnamed: D47.1, J_c3.14
unnamed: D48.1, J_c3.16
unnamed: D49.1, J_c4.2
unnamed: D50.1, J_c4.4
unnamed: D51.1, J_c4.6
unnamed: D52.1, J_c4.8
unnamed: D53.1, J_c4.10
unnamed: D54.1, J_c4.12
unnamed: D55.1, J_c4.14
unnamed: D56.1, J_c4.16
unnamed: D57.1, J_c5.2
unnamed: D58.1, J_c5.4
unnamed: D59.1, J_c5.6
unnamed: D60.1, J_c5.8
unnamed: D61.1, J_c5.10
unnamed: D62.1, J_c5.12
unnamed: D63.1, J_c5.14
unnamed: D64.1, J_c5.16
unnamed: D65.1, J_c6.2
unnamed: D66.1, J_c6.4
unnamed: D67.1, J_c6.6
unnamed: D68.1, J_c6.8
unnamed: D69.1, J_c6.10
unnamed: D70.1, J_c6.12
unnamed: D71.1, J_c6.14
unnamed: D72.1, J_c6.16
unnamed: D73.1, J_c7_r0.2, SW6.2
unnamed: D74.1, J_c7_r1.2, SW7.2
unnamed: D75.1, J_c7_r2.2, SW8.2
unnamed: D76.1, J_c7_r3.2, SW9.2
unnamed: D77.1, J_c7_r4.2, SW10.2
unnamed: D78.1, J26F1.2
unnamed: D79.1, J26G1.2
unnamed: D80.1, J_c7.2
unnamed: J15.1, Q2.2
unnamed: J16.2, R3.2
unnamed: J16.4, R4.2
unnamed: J17.1, U4.11
unnamed: J17.2, R5.2
unnamed: J17.3, U4.12
unnamed: J17.4, R6.2
unnamed: J17.5, U4.13
unnamed: J17.6, R7.2
unnamed: J17.7, U4.14
unnamed: J17.8, R8.2
unnamed: J17.9, U4.15
unnamed: J17.10, R9.2
unnamed: J17.11, U4.16
unnamed: J17.12, R10.2
unnamed: J17.13, U4.17
unnamed: J17.14, R11.2
unnamed: J17.15, U4.18
unnamed: J17.16, R12.2
unnamed: J18.1, U5.11
unnamed: J18.2, R13.2
unnamed: J18.3, U5.12
unnamed: J18.4, R14.2
unnamed: J18.5, U5.13
unnamed: J18.6, R15.2
unnamed: J18.7, U5.14
unnamed: J18.8, R16.2
unnamed: J18.9, U5.15
unnamed: J18.10, R17.2
unnamed: J18.11, U5.16
unnamed: J18.12, R18.2
unnamed: J18.13, U5.17
unnamed: J18.14, R19.2
unnamed: J18.15, U5.18
unnamed: J18.16, R20.2
unnamed: Q1.1, R21.1, R23.2
unnamed: Q2.1, R22.1, R24.2

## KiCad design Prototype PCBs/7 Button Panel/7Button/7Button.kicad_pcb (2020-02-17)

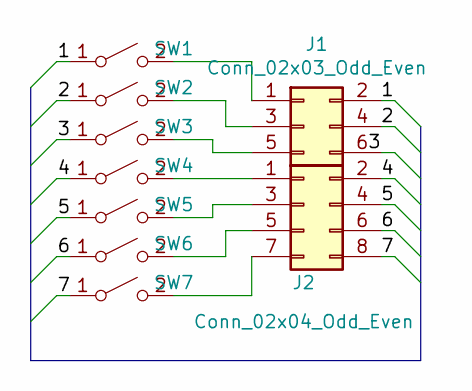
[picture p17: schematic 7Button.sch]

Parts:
J1: Conn_02x03_Odd_Even; PinHeader_2x03_P2.54mm_Vertical
J2: Conn_02x04_Odd_Even; PinHeader_2x04_P2.54mm_Vertical
SW1, SW2, SW3, SW4, SW5, SW6, SW7: SW_SPST; SW_PUSH-12mm_widepinholes

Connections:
/1: J1.2, SW1.1 (A)
/2: J1.4, SW2.1 (A)
/3: J1.6, SW3.1 (A)
/4: J2.2, SW4.1 (A)
/5: J2.4, SW5.1 (A)
/6: J2.6, SW6.1 (A)
/7: J2.8, SW7.1 (A)
unnamed: J1.1, SW1.2 (B)
unnamed: J1.3, SW2.2 (B)
unnamed: J1.5, SW3.2 (B)
unnamed: J2.1, SW4.2 (B)
unnamed: J2.3, SW5.2 (B)
unnamed: J2.5, SW6.2 (B)
unnamed: J2.7, SW7.2 (B)

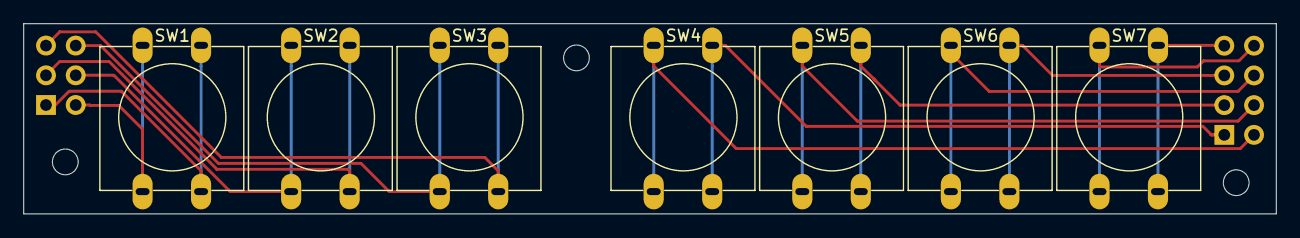
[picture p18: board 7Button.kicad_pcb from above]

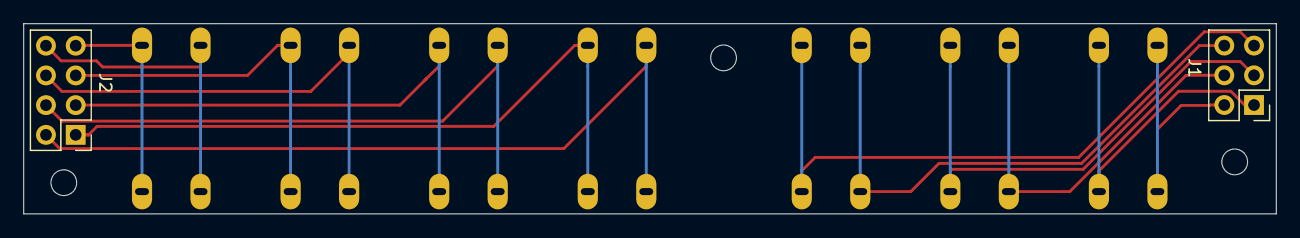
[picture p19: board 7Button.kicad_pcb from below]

Board: 2 copper layers, 107.1 x 16.3 mm, 9 parts (2 on the bottom side), 14 nets.

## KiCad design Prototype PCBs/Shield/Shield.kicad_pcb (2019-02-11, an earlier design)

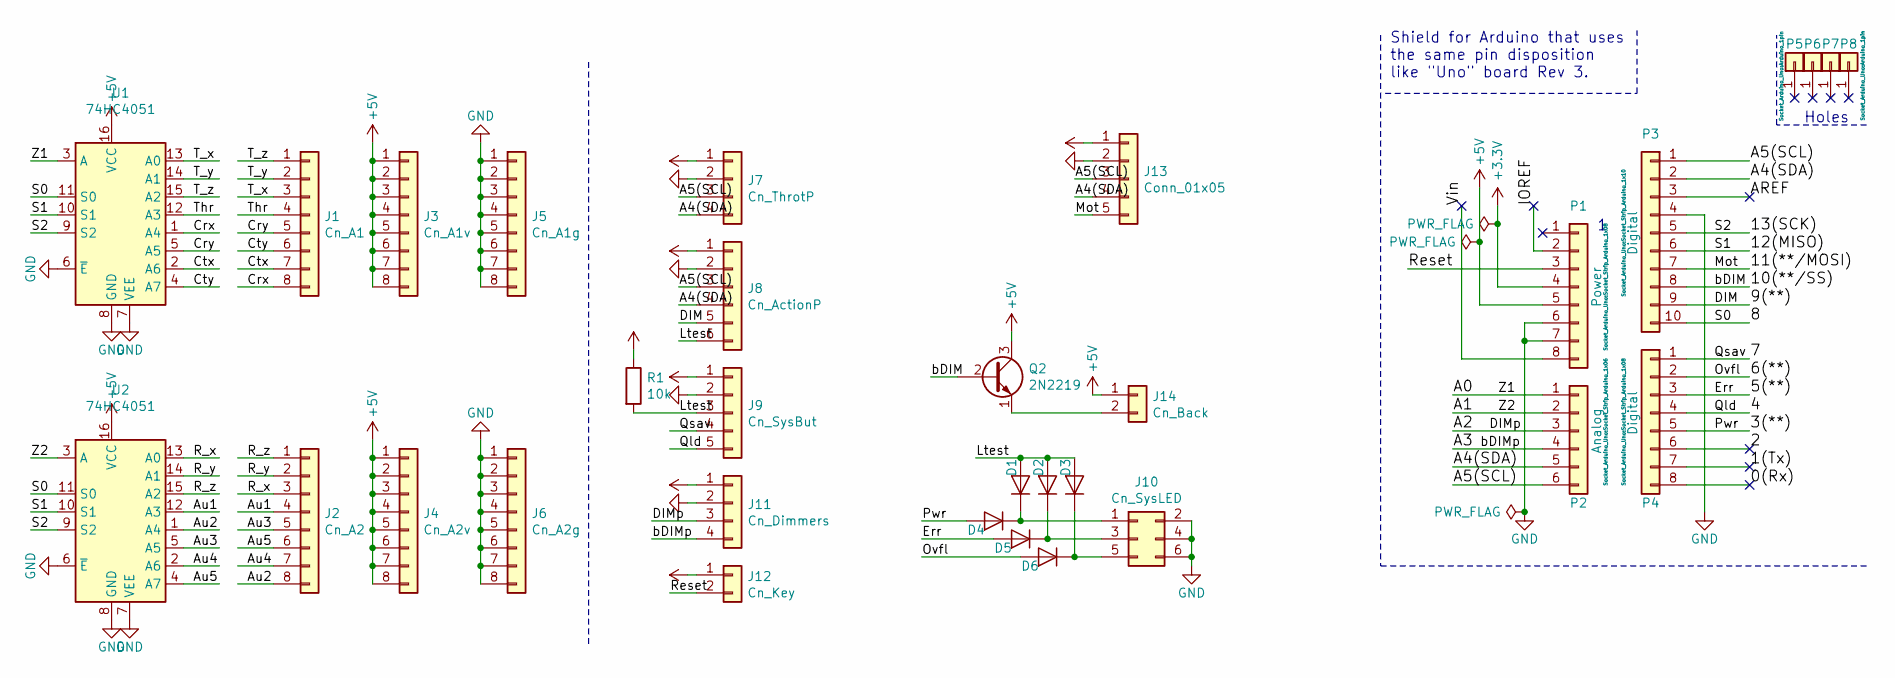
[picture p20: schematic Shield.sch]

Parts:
D1, D2, D3, D4, D5, D6: D; D_DO-35_SOD27_P7.62mm_Horizontal
J1: Cn_A1; PinHeader_1x08_P2.54mm_Vertical
J2: Cn_A2; PinHeader_1x08_P2.54mm_Vertical
J3: Cn_A1v; PinHeader_1x08_P2.54mm_Vertical
J4: Cn_A2v; PinHeader_1x08_P2.54mm_Vertical
J5: Cn_A1g; PinHeader_1x08_P2.54mm_Vertical
J6: Cn_A2g; PinHeader_1x08_P2.54mm_Vertical
J7: Cn_ThrotP; PinHeader_1x04_P2.54mm_Vertical
J8: Cn_ActionP; PinHeader_1x06_P2.54mm_Vertical
J9: Cn_SysBut; PinHeader_1x05_P2.54mm_Vertical
J10: Cn_SysLED; PinSocket_2x03_P2.54mm_Vertical
J11: Cn_Dimmers; PinHeader_1x04_P2.54mm_Vertical
J12: Cn_Key; PinHeader_1x02_P2.54mm_Vertical
J13: Conn_01x05; PinHeader_1x05_P2.54mm_Vertical
J14: Cn_Back; PinHeader_1x02_P2.54mm_Vertical
P1: Power; Socket_Strip_Arduino_1x08
P2: Analog; Socket_Strip_Arduino_1x06
P3: Digital; Socket_Strip_Arduino_1x10
P4: Digital; Socket_Strip_Arduino_1x08
P5, P6, P7, P8: CONN_01X01; Arduino_1pin
Q2: 2N2219; TO-92_HandSolder
R1: 10k; R_Axial_DIN0207_L6.3mm_D2.5mm_P7.62mm_Horizontal
U1, U2: 74HC4051; DIP-16_W7.62mm_Socket

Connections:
+3V3: P1.4
+5V: J3.1, J3.2, J3.3, J3.4, J3.5, J3.6, J3.7, J3.8, J4.1, J4.2, J4.3, J4.4, J4.5, J4.6, J4.7, J4.8, J7.1, J8.1, J9.1, J11.1, J12.1, J13.1, J14.1, P1.5, Q2.3 (C), R1.1, U1.16 (VCC), U2.16 (VCC)
/0(Rx): P4.8
/1(Tx): P4.7
/2: P4.6
/3(**): D4.2 (A), P4.5
/4: J9.5, P4.4
/5(**): D5.2 (A), P4.3
/6(**): D6.2 (A), P4.2
/7: J9.4, P4.1
/8: P3.10, U1.11 (S0), U2.11 (S0)
/9(**): J8.5, P3.9
/10(**/SS): P3.8, Q2.2 (B)
/11(**/MOSI): J13.5, P3.7
/12(MISO): P3.6, U1.10 (S1), U2.10 (S1)
/13(SCK): P3.5, U1.9 (S2), U2.9 (S2)
/A0: P2.1, U1.3 (A)
/A1: P2.2, U2.3 (A)
/A2: J11.3, P2.3
/A3: J11.4, P2.4
/A4(SDA): J7.4, J8.4, J13.4, P2.5, P3.2
/A5(SCL): J7.3, J8.3, J13.3, P2.6, P3.1
/AREF: P3.3
/Au1: J2.4, U2.12 (A3)
/Au2: J2.8, U2.1 (A4)
/Au3: J2.5, U2.5 (A5)
/Au4: J2.7, U2.2 (A6)
/Au5: J2.6, U2.4 (A7)
/Crx: J1.8, U1.1 (A4)
/Cry: J1.5, U1.5 (A5)
/Ctx: J1.7, U1.2 (A6)
/Cty: J1.6, U1.4 (A7)
/IOREF: P1.2
/Ltest: D1.2 (A), D2.2 (A), D3.2 (A), J8.6, J9.3, R1.2
/R_x: J2.3, U2.13 (A0)
/R_y: J2.2, U2.14 (A1)
/R_z: J2.1, U2.15 (A2)
/Reset: J12.2, P1.3
/T_x: J1.3, U1.13 (A0)
/T_y: J1.2, U1.14 (A1)
/T_z: J1.1, U1.15 (A2)
/Thr: J1.4, U1.12 (A3)
/Vin: P1.8
GND: J5.1, J5.2, J5.3, J5.4, J5.5, J5.6, J5.7, J5.8, J6.1, J6.2, J6.3, J6.4, J6.5, J6.6, J6.7, J6.8, J7.2, J8.2, J9.2, J10.2, J10.4, J10.6, J11.2, J13.2, P1.6, P1.7, P3.4, U1.6 (~E), U1.7 (VEE), U1.8 (GND), U2.6 (~E), U2.7 (VEE), U2.8 (GND)
unnamed: D1.1 (K), D4.1 (K), J10.1
unnamed: D2.1 (K), D5.1 (K), J10.3
unnamed: D3.1 (K), D6.1 (K), J10.5
unnamed: J14.2, Q2.1 (E)

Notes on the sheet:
Holes
Shield for Arduino that uses the same pin disposition like "Uno" board Rev 3.

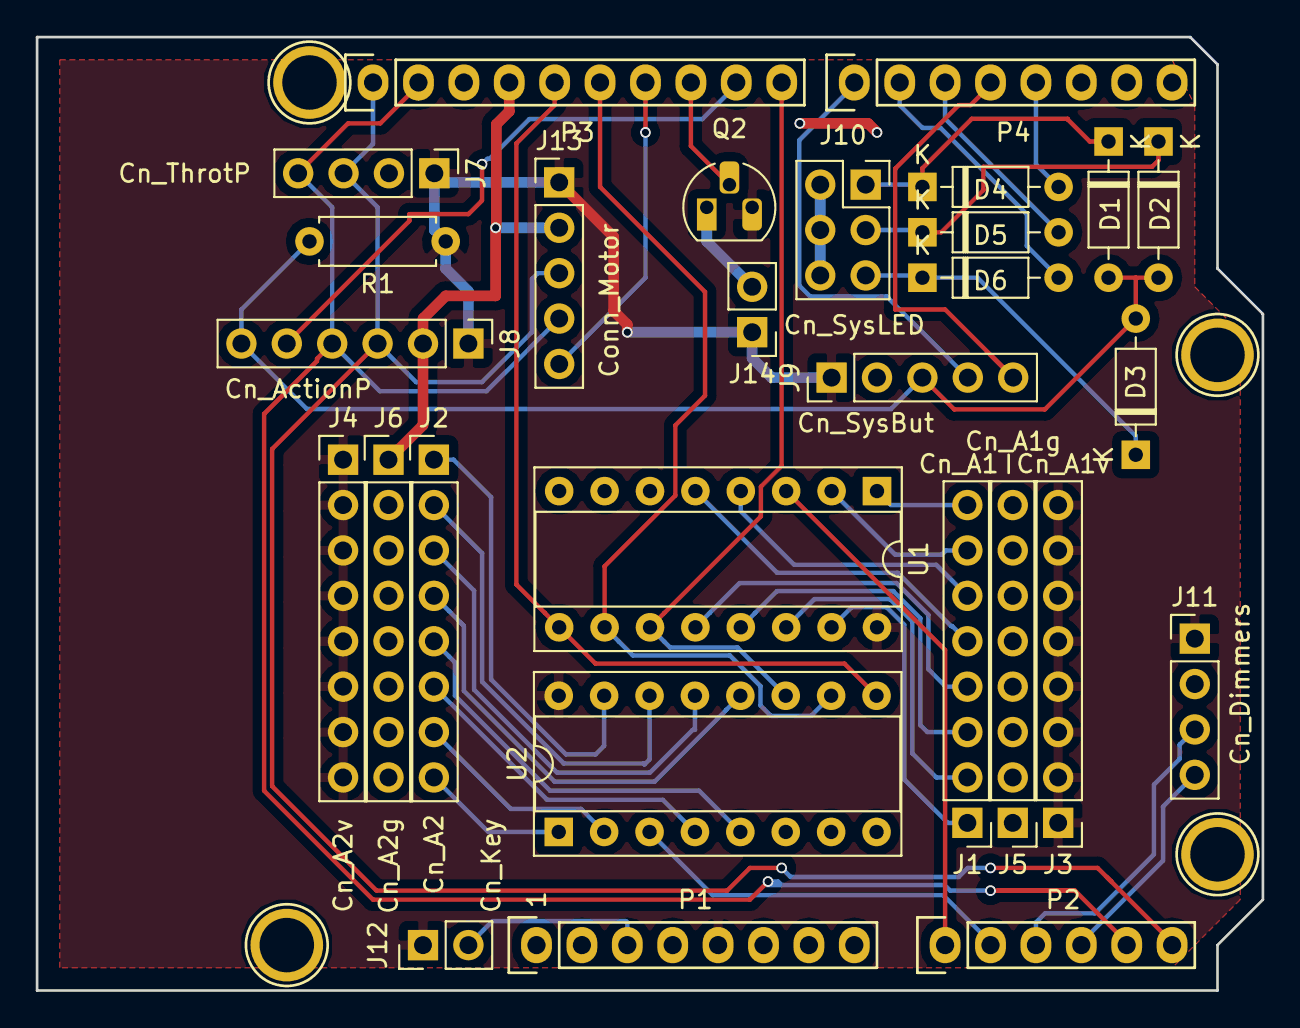
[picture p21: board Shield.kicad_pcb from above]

Board: 2 copper layers, 68.6 x 53.3 mm, 32 parts (0 on the bottom side), 41 nets.

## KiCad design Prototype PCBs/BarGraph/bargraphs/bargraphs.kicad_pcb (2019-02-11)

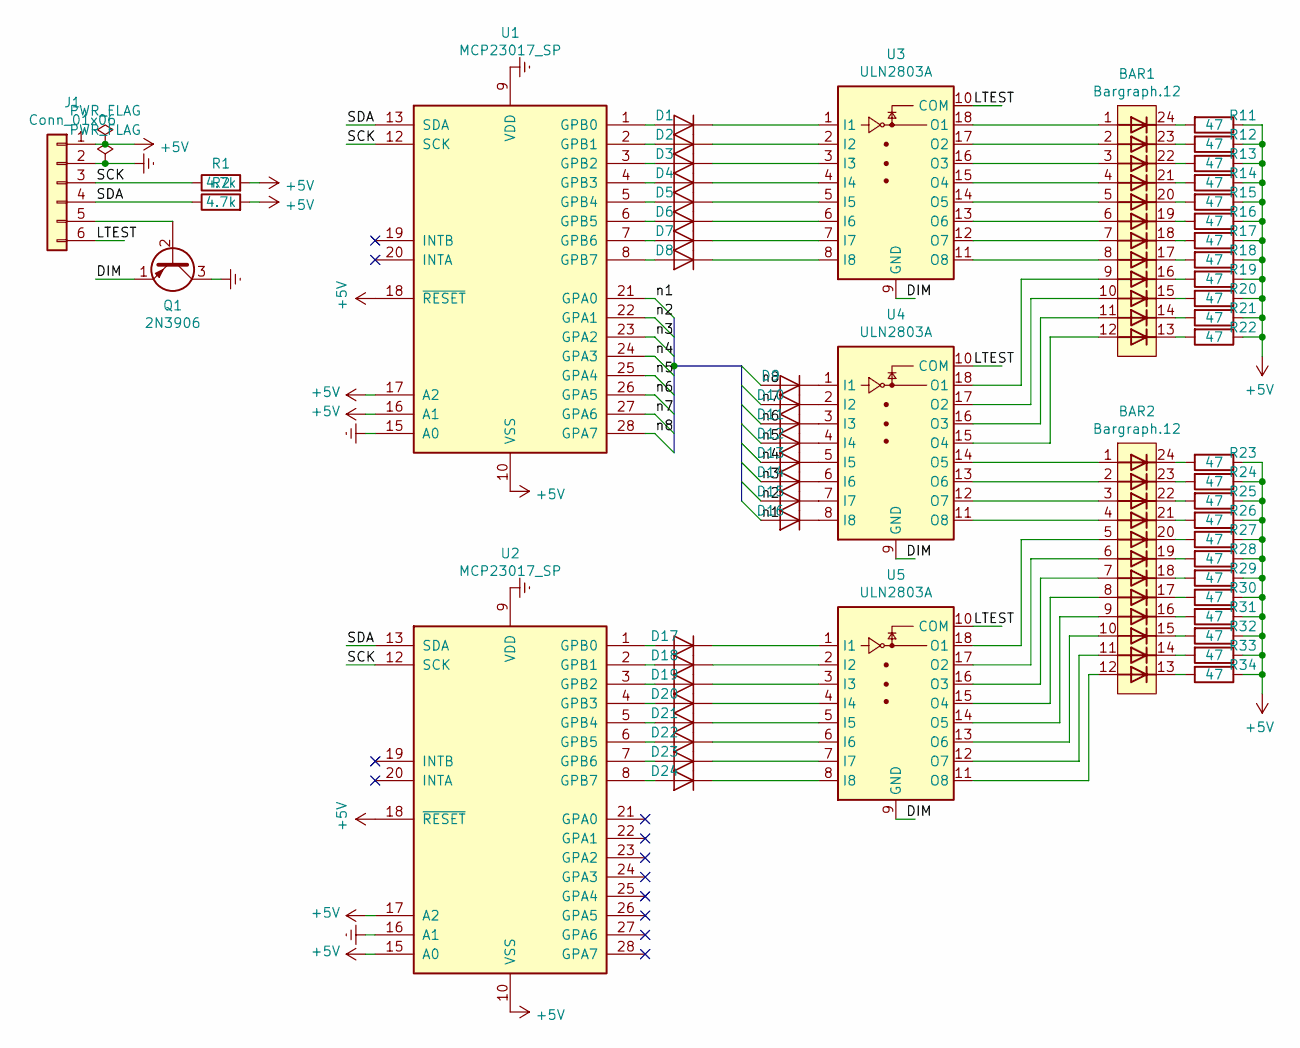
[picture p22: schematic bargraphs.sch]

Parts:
BAR1, BAR2: Bargraph.12; BarGraph.12
D1, D2, D3, D4, D5, D6, D7, D8, D9, D10, D11, D12, D13, D14, D15, D16, D17, D18, D19, D20, D21, D22, D23, D24: D; D_DO-35_SOD27_P7.62mm_Horizontal
J1: Conn_01x06; PinHeader_1x06_P2.54mm_Vertical
Q1: 2N3906; TO-92_Inline
R1, R2: 4.7k; R_Axial_DIN0207_L6.3mm_D2.5mm_P7.62mm_Horizontal
R11, R12, R13, R14, R15, R16, R17, R18, R19, R20, R21, R22, R23, R24, R25, R26, R27, R28, R29, R30, R31, R32, R33, R34: 47; R_Axial_DIN0207_L6.3mm_D2.5mm_P7.62mm_Horizontal
U1, U2: MCP23017_SP; DIP-28_W7.62mm_Socket
U3, U4, U5: ULN2803A; DIP-18_W7.62mm_Socket

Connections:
+5V: J1.1, R1.2, R2.2, R11.1, R12.1, R13.1, R14.1, R15.1, R16.1, R17.1, R18.1, R19.1, R20.1, R21.1, R22.1, R23.1, R24.1, R25.1, R26.1, R27.1, R28.1, R29.1, R30.1, R31.1, R32.1, R33.1, R34.1, U1.10 (VSS), U1.16 (A1), U1.17 (A2), U1.18 (~RESET~), U2.10 (VSS), U2.15 (A0), U2.17 (A2), U2.18 (~RESET~)
/DIM: Q1.1 (E), U3.9 (GND), U4.9 (GND), U5.9 (GND)
/LTEST: J1.6, U3.10 (COM), U4.10 (COM), U5.10 (COM)
/SCK: J1.3, R1.1, U1.12 (SCK), U2.12 (SCK)
/SDA: J1.4, R2.1, U1.13 (SDA), U2.13 (SDA)
/n1: D16.2 (A), U1.21 (GPA0)
/n2: D15.2 (A), U1.22 (GPA1)
/n3: D14.2 (A), U1.23 (GPA2)
/n4: D13.2 (A), U1.24 (GPA3)
/n5: D12.2 (A), U1.25 (GPA4)
/n6: D11.2 (A), U1.26 (GPA5)
/n7: D10.2 (A), U1.27 (GPA6)
/n8: D9.2 (A), U1.28 (GPA7)
Earth: J1.2, Q1.3 (C), U1.9 (VDD), U1.15 (A0), U2.9 (VDD), U2.16 (A1)
unnamed: BAR1.1 (A), U3.18 (O1)
unnamed: BAR1.2 (A), U3.17 (O2)
unnamed: BAR1.3 (A), U3.16 (O3)
unnamed: BAR1.4 (A), U3.15 (O4)
unnamed: BAR1.5 (A), U3.14 (O5)
unnamed: BAR1.6 (A), U3.13 (O6)
unnamed: BAR1.7 (A), U3.12 (O7)
unnamed: BAR1.8 (A), U3.11 (O8)
unnamed: BAR1.9 (A), U4.18 (O1)
unnamed: BAR1.10 (A), U4.17 (O2)
unnamed: BAR1.11 (A), U4.16 (O3)
unnamed: BAR1.12 (A), U4.15 (O4)
unnamed: BAR1.13 (K), R22.2
unnamed: BAR1.14 (K), R21.2
unnamed: BAR1.15 (K), R20.2
unnamed: BAR1.16 (K), R19.2
unnamed: BAR1.17 (K), R18.2
unnamed: BAR1.18 (K), R17.2
unnamed: BAR1.19 (K), R16.2
unnamed: BAR1.20 (K), R15.2
unnamed: BAR1.21 (K), R14.2
unnamed: BAR1.22 (K), R13.2
unnamed: BAR1.23 (K), R12.2
unnamed: BAR1.24 (K), R11.2
unnamed: BAR2.1 (A), U4.14 (O5)
unnamed: BAR2.2 (A), U4.13 (O6)
unnamed: BAR2.3 (A), U4.12 (O7)
unnamed: BAR2.4 (A), U4.11 (O8)
unnamed: BAR2.5 (A), U5.18 (O1)
unnamed: BAR2.6 (A), U5.17 (O2)
unnamed: BAR2.7 (A), U5.16 (O3)
unnamed: BAR2.8 (A), U5.15 (O4)
unnamed: BAR2.9 (A), U5.14 (O5)
unnamed: BAR2.10 (A), U5.13 (O6)
unnamed: BAR2.11 (A), U5.12 (O7)
unnamed: BAR2.12 (A), U5.11 (O8)
unnamed: BAR2.13 (K), R34.2
unnamed: BAR2.14 (K), R33.2
unnamed: BAR2.15 (K), R32.2
unnamed: BAR2.16 (K), R31.2
unnamed: BAR2.17 (K), R30.2
unnamed: BAR2.18 (K), R29.2
unnamed: BAR2.19 (K), R28.2
unnamed: BAR2.20 (K), R27.2
unnamed: BAR2.21 (K), R26.2
unnamed: BAR2.22 (K), R25.2
unnamed: BAR2.23 (K), R24.2
unnamed: BAR2.24 (K), R23.2
unnamed: D1.1 (K), U3.1 (I1)
unnamed: D1.2 (A), U1.1 (GPB0)
unnamed: D2.1 (K), U3.2 (I2)
unnamed: D2.2 (A), U1.2 (GPB1)
unnamed: D3.1 (K), U3.3 (I3)
unnamed: D3.2 (A), U1.3 (GPB2)
unnamed: D4.1 (K), U3.4 (I4)
unnamed: D4.2 (A), U1.4 (GPB3)
unnamed: D5.1 (K), U3.5 (I5)
unnamed: D5.2 (A), U1.5 (GPB4)
unnamed: D6.1 (K), U3.6 (I6)
unnamed: D6.2 (A), U1.6 (GPB5)
unnamed: D7.1 (K), U3.7 (I7)
unnamed: D7.2 (A), U1.7 (GPB6)
unnamed: D8.1 (K), U3.8 (I8)
unnamed: D8.2 (A), U1.8 (GPB7)
unnamed: D9.1 (K), U4.1 (I1)
unnamed: D10.1 (K), U4.2 (I2)
unnamed: D11.1 (K), U4.3 (I3)
unnamed: D12.1 (K), U4.4 (I4)
unnamed: D13.1 (K), U4.5 (I5)
unnamed: D14.1 (K), U4.6 (I6)
unnamed: D15.1 (K), U4.7 (I7)
unnamed: D16.1 (K), U4.8 (I8)
unnamed: D17.1 (K), U5.1 (I1)
unnamed: D17.2 (A), U2.1 (GPB0)
unnamed: D18.1 (K), U5.2 (I2)
unnamed: D18.2 (A), U2.2 (GPB1)
unnamed: D19.1 (K), U5.3 (I3)
unnamed: D19.2 (A), U2.3 (GPB2)
unnamed: D20.1 (K), U5.4 (I4)
unnamed: D20.2 (A), U2.4 (GPB3)
unnamed: D21.1 (K), U5.5 (I5)
unnamed: D21.2 (A), U2.5 (GPB4)
unnamed: D22.1 (K), U5.6 (I6)
unnamed: D22.2 (A), U2.6 (GPB5)
unnamed: D23.1 (K), U5.7 (I7)
unnamed: D23.2 (A), U2.7 (GPB6)
unnamed: D24.1 (K), U5.8 (I8)
unnamed: D24.2 (A), U2.8 (GPB7)
unnamed: J1.5, Q1.2 (B)

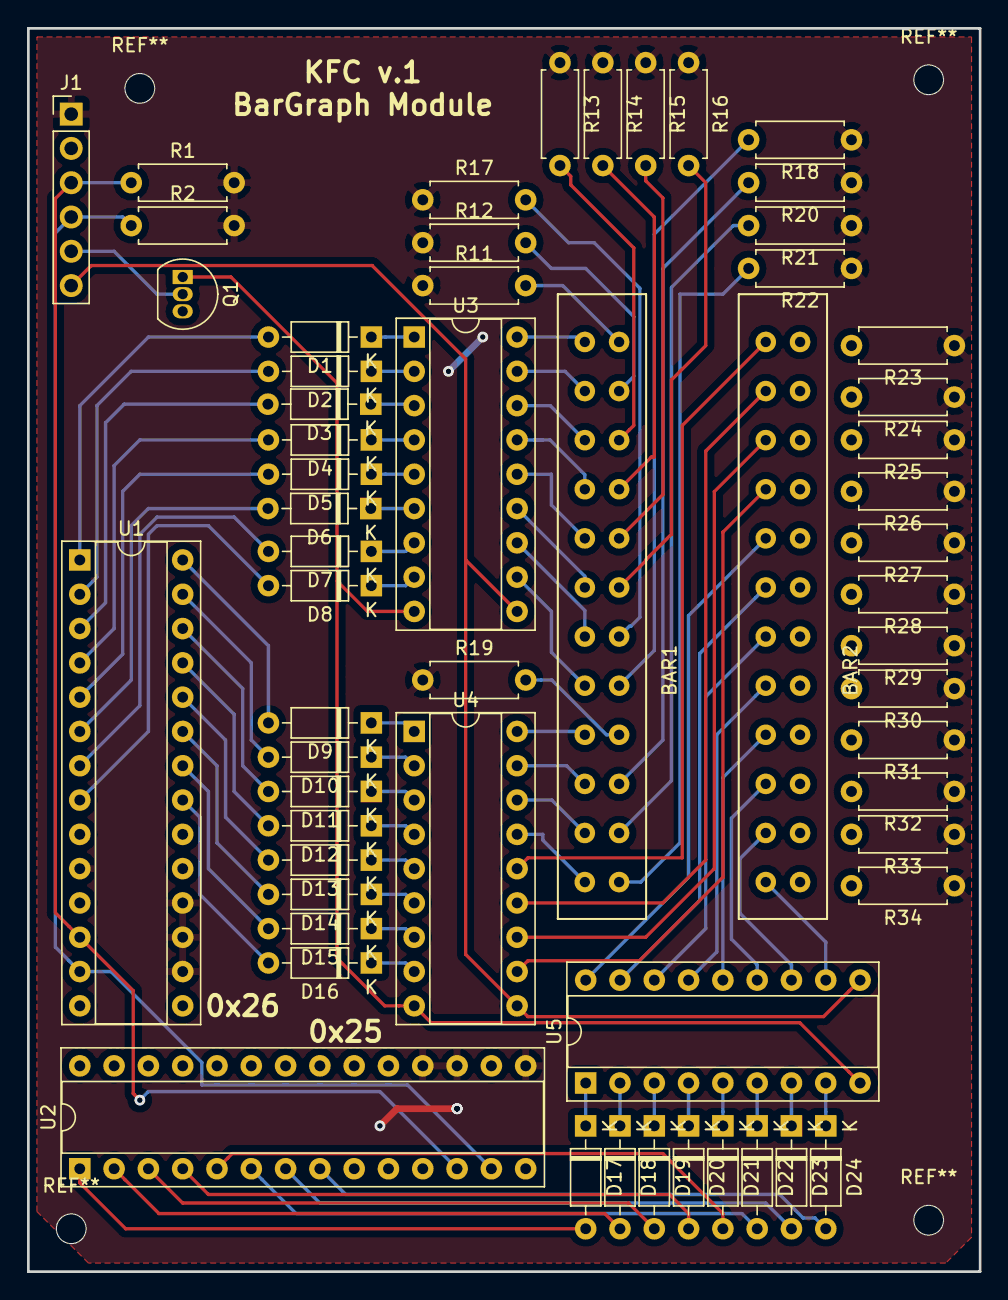
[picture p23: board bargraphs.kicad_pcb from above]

Board: 2 copper layers, 70.5 x 92.1 mm, 59 parts (0 on the bottom side), 103 nets.

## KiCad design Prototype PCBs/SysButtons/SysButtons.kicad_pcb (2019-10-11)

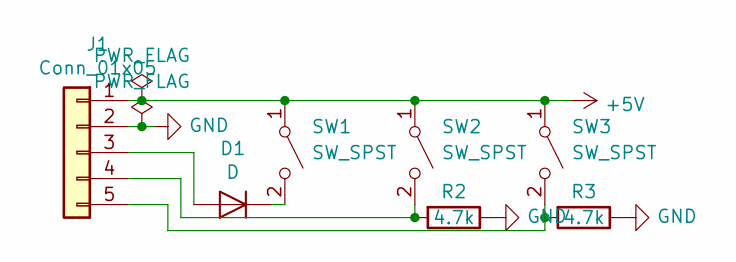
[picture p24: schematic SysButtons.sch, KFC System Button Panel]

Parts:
D1: D; D_DO-35_SOD27_P7.62mm_Horizontal
J1: Conn_01x05; PinHeader_1x05_P2.54mm_Vertical
R2, R3: 4.7k; R_Axial_DIN0207_L6.3mm_D2.5mm_P7.62mm_Horizontal
SW1, SW2, SW3: SW_SPST; SW_PUSH-12mm_widepinholes

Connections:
+5V: J1.1, SW1.1 (A), SW2.1 (A), SW3.1 (A)
GND: J1.2, R2.1, R3.1
unnamed: D1.1 (K), SW1.2 (B)
unnamed: D1.2 (A), J1.3
unnamed: J1.4, R2.2, SW2.2 (B)
unnamed: J1.5, R3.2, SW3.2 (B)

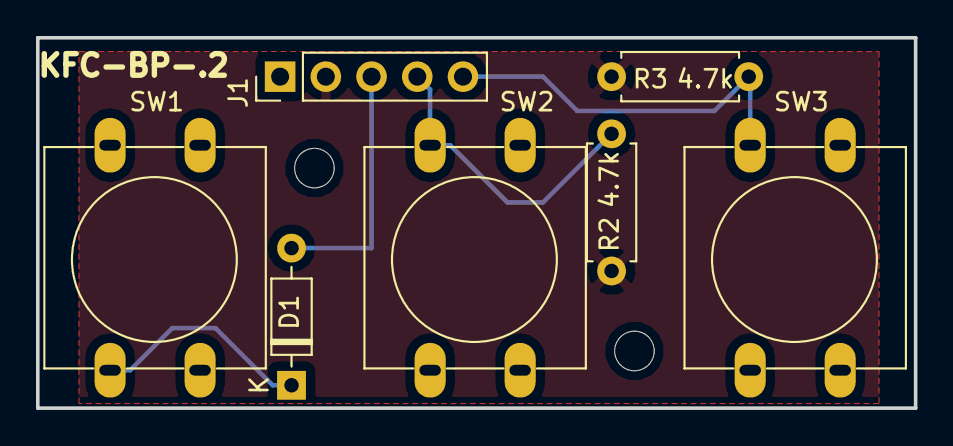
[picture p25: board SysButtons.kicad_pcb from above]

Board: 2 copper layers, 48.8 x 20.6 mm, 7 parts (0 on the bottom side), 6 nets.

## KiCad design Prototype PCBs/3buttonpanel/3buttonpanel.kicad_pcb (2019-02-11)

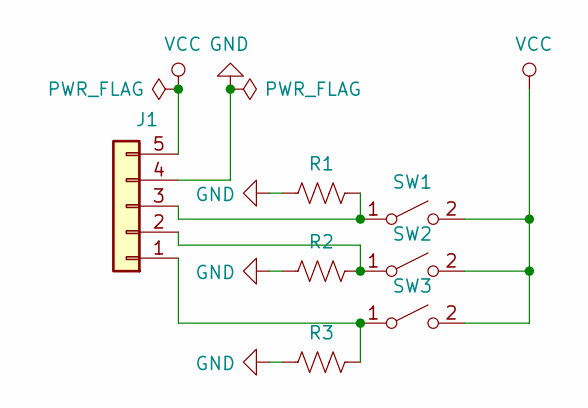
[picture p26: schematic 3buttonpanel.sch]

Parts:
J1: Conn_01x05; PinHeader_1x05_P2.54mm_Vertical
R1, R2, R3: R_US; R_Axial_DIN0207_L6.3mm_D2.5mm_P10.16mm_Horizontal
SW1, SW2, SW3: SW_SPST; SW_PUSH-12mm

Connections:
GND: J1.4, R1.1, R2.1, R3.1
unnamed: J1.1, R3.2, SW3.1 (A)
unnamed: J1.2, R2.2, SW2.1 (A)
unnamed: J1.3, R1.2, SW1.1 (A)
VCC: J1.5, SW1.2 (B), SW2.2 (B), SW3.2 (B)


Board: 2 copper layers, 22.9 x 63.5 mm, 7 parts (0 on the bottom side), 5 nets.

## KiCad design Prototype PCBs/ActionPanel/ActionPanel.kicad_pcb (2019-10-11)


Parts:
D1, D2, D3, D4, D5, D6, D7, D8, D9, D10, D11, D12, D13, D14, D15, D16: D; D_DO-35_SOD27_P7.62mm_Horizontal
J1: Conn_01x06; PinSocket_1x06_P2.54mm_Vertical
J2, J3, J5, J6, J8: Conn_02x06_Odd_Even; PinSocket_2x06_P2.54mm_Vertical
J4, J7: Conn_02x04_Odd_Even; PinSocket_2x04_P2.54mm_Vertical
Q1: 2N3906; TO-92_Inline
R1, R2, R13, R14, R15, R16, R17, R18, R19, R20, R23, R24, R25, R26, R27, R28, R29, R30, R32, R33, R34, R35, R36, R37, R38, R39, R40, R41, R42, R43, R44, R45, R46: R; R_Axial_DIN0204_L3.6mm_D1.6mm_P7.62mm_Horizontal
R7, R8, R9, R10, R11, R12: 100; R_Axial_DIN0204_L3.6mm_D1.6mm_P7.62mm_Horizontal
R31: 4.7k; R_Axial_DIN0204_L3.6mm_D1.6mm_P7.62mm_Horizontal
SW1, SW2, SW3, SW4, SW5, SW6, SW7, SW8, SW9, SW10: SW_SPST; SW_PUSH-12mm
U1, U4, U5: MCP23017_SP; DIP-28_W7.62mm_Socket
U2, U3: ULN2803A; DIP-18_W7.62mm_Socket

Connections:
+5V: J1.6, J2.2, J2.4, J2.6, J2.8, J2.10, J2.12, J3.2, J3.4, J3.6, J3.8, J3.10, J3.12, J4.2, J4.4, J4.6, J4.8, R1.1, R2.1, SW1.2 (B), SW2.2 (B), SW3.2 (B), SW4.2 (B), SW5.2 (B), SW6.2 (B), SW7.2 (B), SW8.2 (B), SW9.2 (B), SW10.2 (B), U1.9 (VDD), U1.15 (A0), U1.16 (A1), U1.17 (A2), U1.18 (~RESET~), U4.9 (VDD), U4.15 (A0), U4.18 (~RESET~), U5.9 (VDD), U5.18 (~RESET~)
/AG1: R36.2, SW1.1 (A), U5.1 (GPB0)
/AG2: R37.2, SW2.1 (A), U5.2 (GPB1)
/AG3: R38.2, SW3.1 (A), U5.3 (GPB2)
/AG4: R39.2, SW4.1 (A), U5.4 (GPB3)
/AG5: R40.2, SW5.1 (A), U5.5 (GPB4)
/AG6: R41.2, SW6.1 (A), U5.6 (GPB5)
/AG7: R42.2, SW7.1 (A), U5.7 (GPB6)
/AG8: R43.2, SW8.1 (A), U5.8 (GPB7)
/AG9: R44.2, SW9.1 (A), U5.28 (GPA7)
/AG10: R45.2, SW10.1 (A), U5.27 (GPA6)
/ASW: J8.11, R46.2, U5.26 (GPA5)
/ATB: J6.11, R30.2, U4.24 (GPA3)
/BRKL: R9.1, U3.15 (O4)
/BSW: J8.5, R33.2, U5.23 (GPA2)
/DIM: Q1.1 (E), U2.9 (GND), U3.9 (GND)
/GRL: R8.1, U3.14 (O5)
/GSW: J8.3, R32.2, U5.22 (GPA1)
/LGTL: R7.1, U3.13 (O6)
/LSW: J8.1, R31.2, U5.21 (GPA0)
/LTEST: J1.1, U2.10 (COM), U3.10 (COM)
/RCSL: R10.1, U3.16 (O3)
/RST: J7.1, R17.2, U4.25 (GPA4)
/RSW: J8.7, R34.2, U5.24 (GPA3)
/SAS1: J5.1, R13.2, U4.1 (GPB0)
/SAS2: J5.3, R15.2, U4.2 (GPB1)
/SAS3: J5.5, R18.2, U4.3 (GPB2)
/SAS4: J5.7, R23.2, U4.4 (GPB3)
/SAS5: J5.9, R26.2, U4.5 (GPB4)
/SAS6: J5.11, R29.2, U4.6 (GPB5)
/SAS7: J6.1, R14.2, U4.7 (GPB6)
/SAS8: J6.3, R16.2, U4.8 (GPB7)
/SAS9: J6.5, R19.2, U4.21 (GPA0)
/SAS10: J6.7, R24.2, U4.22 (GPA1)
/SASC: J6.9, R27.2, U4.23 (GPA2)
/SASL1: J2.11, U2.11 (O8)
/SASL2: J2.9, U2.12 (O7)
/SASL3: J2.7, U2.13 (O6)
/SASL4: J2.5, U2.14 (O5)
/SASL5: J2.3, U2.15 (O4)
/SASL6: J2.1, U2.16 (O3)
/SASL7: J3.11, U2.17 (O2)
/SASL8: J3.9, U2.18 (O1)
/SASL9: J3.7, U3.11 (O8)
/SASL10: J3.5, U3.12 (O7)
/SCK: J1.4, R2.2, U1.12 (SCK), U4.12 (SCK), U5.12 (SCK)
/SDA: J1.3, R1.2, U1.13 (SDA), U4.13 (SDA), U5.13 (SDA)
/STSW: J8.9, R35.2, U5.25 (GPA4)
/UNI1: R11.1, U3.17 (O2)
/UNI2: R12.1, U3.18 (O1)
/UNO1: J7.3, R20.2, U4.26 (GPA5)
/UNO2: J7.5, R25.2, U4.27 (GPA6)
/UNO3: J7.7, R28.2, U4.28 (GPA7)
GND: J1.5, J5.2, J5.4, J5.6, J5.8, J5.10, J5.12, J6.2, J6.4, J6.6, J6.8, J6.10, J6.12, J7.2, J7.4, J7.6, J7.8, J8.2, J8.4, J8.6, J8.8, J8.10, J8.12, Q1.3 (C), R13.1, R14.1, R15.1, R16.1, R17.1, R18.1, R19.1, R20.1, R23.1, R24.1, R25.1, R26.1, R27.1, R28.1, R29.1, R30.1, R31.1, R32.1, R33.1, R34.1, R35.1, R36.1, R37.1, R38.1, R39.1, R40.1, R41.1, R42.1, R43.1, R44.1, R45.1, R46.1, U1.10 (VSS), U4.10 (VSS), U4.16 (A1), U4.17 (A2), U5.10 (VSS), U5.15 (A0), U5.16 (A1), U5.17 (A2)
unnamed: D1.1 (K), U2.8 (I8)
unnamed: D1.2 (A), U1.1 (GPB0)
unnamed: D2.1 (K), U2.7 (I7)
unnamed: D2.2 (A), U1.2 (GPB1)
unnamed: D3.1 (K), U2.6 (I6)
unnamed: D3.2 (A), U1.3 (GPB2)
unnamed: D4.1 (K), U2.5 (I5)
unnamed: D4.2 (A), U1.4 (GPB3)
unnamed: D5.1 (K), U2.4 (I4)
unnamed: D5.2 (A), U1.5 (GPB4)
unnamed: D6.1 (K), U2.3 (I3)
unnamed: D6.2 (A), U1.6 (GPB5)
unnamed: D7.1 (K), U2.2 (I2)
unnamed: D7.2 (A), U1.7 (GPB6)
unnamed: D8.1 (K), U2.1 (I1)
unnamed: D8.2 (A), U1.8 (GPB7)
unnamed: D9.1 (K), U3.8 (I8)
unnamed: D9.2 (A), U1.21 (GPA0)
unnamed: D10.1 (K), U3.7 (I7)
unnamed: D10.2 (A), U1.22 (GPA1)
unnamed: D11.1 (K), U3.6 (I6)
unnamed: D11.2 (A), U1.23 (GPA2)
unnamed: D12.1 (K), U3.5 (I5)
unnamed: D12.2 (A), U1.24 (GPA3)
unnamed: D13.1 (K), U3.4 (I4)
unnamed: D13.2 (A), U1.25 (GPA4)
unnamed: D14.1 (K), U3.3 (I3)
unnamed: D14.2 (A), U1.26 (GPA5)
unnamed: D15.1 (K), U3.2 (I2)
unnamed: D15.2 (A), U1.27 (GPA6)
unnamed: D16.1 (K), U3.1 (I1)
unnamed: D16.2 (A), U1.28 (GPA7)
unnamed: J1.2, Q1.2 (B)
unnamed: J3.1, R8.2
unnamed: J3.3, R7.2
unnamed: J4.1, R9.2
unnamed: J4.3, R10.2
unnamed: J4.5, R11.2
unnamed: J4.7, R12.2


Board: 2 copper layers, 99.6 x 90.2 mm, 80 parts (0 on the bottom side), 93 nets.

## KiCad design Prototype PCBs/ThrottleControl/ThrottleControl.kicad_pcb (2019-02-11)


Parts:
J1: Conn_01x04; PinHeader_1x04_P2.54mm_Vertical
J2: Conn_Warp; PinHeader_1x03_P2.54mm_Vertical
J3: Conn_Pwarp; PinHeader_1x03_P2.54mm_Vertical
J4: Conn_CamZoom; PinHeader_1x03_P2.54mm_Vertical
J5: Conn_VelRot; PinHeader_1x03_P2.54mm_Vertical
J6: Conn_CamRot; PinHeader_1x05_P2.54mm_Vertical
J7: Conn_UNa; PinHeader_1x04_P2.54mm_Vertical
J8: Conn_UNb; PinHeader_1x05_P2.54mm_Vertical
J9: Conn_UNc; PinHeader_1x05_P2.54mm_Vertical
J10: Conn_MapBs; PinHeader_1x03_P2.54mm_Vertical
J11: Conn_VslSw; PinHeader_1x03_P2.54mm_Vertical
J12: Conn_WarpC; PinHeader_1x02_P2.54mm_Vertical
R1, R2, R3, R4, R5, R6, R7, R8, R9, R10, R11, R12, R13, R14, R15, R16, R17, R18, R19, R20, R21, R22, R23: 4.7k; R_Axial_DIN0207_L6.3mm_D2.5mm_P10.16mm_Horizontal
SW1: SW_Rotary12; R25_Rotary
U1, U2: MCP23017_SP; DIP-28_W7.62mm_Socket

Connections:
+5V: J1.1, R1.2, R2.2, SW1.13, U1.9 (VDD), U1.16 (A1), U1.18 (~RESET~), U2.9 (VDD), U2.15 (A0), U2.16 (A1), U2.18 (~RESET~)
/CZ1: J4.2, R13.2, U1.23 (GPA2)
/CZ2: J4.3, R14.2, U1.24 (GPA3)
/Cam1: J6.2, R7.2, U1.5 (GPB4)
/Cam2: J6.3, R8.2, U1.6 (GPB5)
/Cam3: J6.4, R9.2, U1.7 (GPB6)
/Cam4: J6.5, R10.2, U1.8 (GPB7)
/Map: J10.3, R20.2, U2.2 (GPB1)
/MpR: J10.2, R19.2, U2.1 (GPB0)
/PWR1: J3.2, R17.2, U1.27 (GPA6)
/PWR2: J3.3, R18.2, U1.28 (GPA7)
/SCK: J1.3, R1.1, U1.12 (SCK), U2.12 (SCK)
/SDA: J1.4, R2.1, U1.13 (SDA), U2.13 (SDA)
/TH0: R6.2, SW1.1, U1.4 (GPB3)
/TH25: R5.2, SW1.2, U1.3 (GPB2)
/TH50: R4.2, SW1.3, U1.2 (GPB1)
/TH75: R3.2, SW1.4, U1.1 (GPB0)
/TSW1: J11.2, R21.2, U2.3 (GPB2)
/TSW2: J11.3, R22.2, U2.4 (GPB3)
/UNa1: J7.2, U2.6 (GPB5)
/UNa2: J7.3, U2.7 (GPB6)
/UNa3: J7.4, U2.8 (GPB7)
/UNb1: J8.2, U2.21 (GPA0)
/UNb2: J8.3, U2.22 (GPA1)
/UNb3: J8.4, U2.23 (GPA2)
/UNb4: J8.5, U2.24 (GPA3)
/UNc1: J9.2, U2.25 (GPA4)
/UNc2: J9.3, U2.26 (GPA5)
/UNc3: J9.4, U2.27 (GPA6)
/UNc4: J9.5, U2.28 (GPA7)
/VOR: J5.2, R11.2, U1.21 (GPA0)
/VTR: J5.3, R12.2, U1.22 (GPA1)
/WPC: J12.2, R23.2, U2.5 (GPB4)
/WRP1: J2.2, R15.2, U1.25 (GPA4)
/WRP2: J2.3, R16.2, U1.26 (GPA5)
Earth: J1.2, J2.1, J3.1, J4.1, J5.1, J6.1, J7.1, J8.1, J9.1, J10.1, J11.1, J12.1, R3.1, R4.1, R5.1, R6.1, R7.1, R8.1, R9.1, R10.1, R11.1, R12.1, R13.1, R14.1, R15.1, R16.1, R17.1, R18.1, R19.1, R20.1, R21.1, R22.1, R23.1, U1.10 (VSS), U1.15 (A0), U1.17 (A2), U2.10 (VSS), U2.17 (A2)


Board: 2 copper layers, 72.4 x 72.4 mm, 38 parts (0 on the bottom side), 36 nets.

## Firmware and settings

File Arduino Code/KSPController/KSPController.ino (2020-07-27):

#include <Wire.h>

#include "KSPController.h"
#include "utils.h"

//#include <Joystick.h>
//#define JOYSTICK_COUNT 2
//
//Joystick_ Joystick[JOYSTICK_COUNT] = {  
//  Joystick_(0x01, JOYSTICK_TYPE_MULTI_AXIS, 32, 0, false, true, false, true, false, false, true, true, false, false, false),
//  Joystick_(0x02, JOYSTICK_TYPE_MULTI_AXIS, 32, 1, true, true, false, true, true, false, false, false, true, true, true)
//};

void setup() {

  /* Pin Setup */
  for (int i=0; i <= sizeof outputs; i++) {
    pinMode(i, OUTPUT);
  }
  for (int i=0; i <= sizeof outputs; i++) {
    pinMode(i, OUTPUT);
  }

  /* turn on all the lights during the start up for a BIT check */
  digitalWrite(p.powerled, HIGH);
  digitalWrite(p.errled, HIGH);

  /* set unused analogue input pins as digital outs forced low to prevent noise */
//  for (i = A1; i <= A3; i++) {
//    pinMode(i, OUTPUT);
//    digitalWrite(i, LOW);
//  }

  /* wake up the I2C_bus */
  Wire.begin();

  /* start serial comms */
  Serial.begin();
  #ifdef DEBUG
  Serial.println("<Arduino is ready>");
  #endif

  /* hold to allow light BIT to be seen */
  delay(c_light_bit_time);
  digitalWrite(p.powerled, LOW);
  digitalWrite(p.errled, LOW);
  //digitalWrite(c_overrun_led_pin, LOW);

  /* Setup Pins for Analog Multiplexing */
  for (i=0; i<3; i++)
  {
    pinMode(selectPins[i], OUTPUT);
    digitalWrite(selectPins[i], HIGH);
  }

  /* Setup i2c multiplexers */
  mux_Tx(add.matrix, IODIRA, 0x00); // Set IODIR of register A to output (0). GPIOB defaults input
  mux_Tx(add.ledc, IODIRA, 00x00); // Set led io expander banks to output
  mux_Tx(add.ledc, IODIRB, 00x00);
}

/* main code loop */
void loop() {

  /* work out if we are ready for the next frame. As this is real time we need to allow
    for the processing time and run a fixed start delay
  */
  t_current_frame = millis();  /* frame start time */
  t_frame_time = t_current_frame - t_last_frame;  /* time since last frame */
  t_run_time = t_current_frame - t_power_on; /* keep track of time since power on */

  if (t_frame_time >= c_frame_time_target) { /* its time to run */
    t_last_frame = t_current_frame;

    /* check if data received, if so read it in */
    if (Serial.available() == sizeof(x_inputbuffer)) {
      Serial.readBytes(x_inputbuffer, sizeof(x_inputbuffer));
      if (x_inputbuffer[0] == 0x00) {
        f_data_requested = TRUE;
      }
      else if (x_inputbuffer[0] == 0x01) {
        f_data_received = TRUE;
      }
      t_last_serial_time = 0;
    }
    else {
      t_last_serial_time += t_frame_time;
    }

    /* DEBUG - Removes requirement for a valid serial connection, allowing testing without game running */
    #ifdef DEBUG
    t_last_serial_time = 0;
    #endif
    
    t_power_on = t_current_frame;
    f_power_on_first_pass = FALSE;
    //digitalWrite(c_error_led_pin, LOW);

    /* Manage the dimmer input  */
     
      x_dimmer_setting = 1023; //map(analogRead(A2), 0, 1023, 255, 2); /* Dimmer - REVERSED - set a minimum to avoid no lights */
      /* Turn on the power light */
      light_dim_ctl(c_power_led_pin, true, x_dimmer_setting, 0);

      if (t_last_serial_time >= c_serial_timeout) {
        /* no data from the main program, turn off all the lights and flash the error light */
//        mux_Tx(0x23, 0x12, 0x00);  /* MUX 0x23, GPIOA */
//        mux_Tx(0x23, 0x13, 0x00);  /* MUX 0x23, GPIOB */
//        mux_Tx(0x24, 0x12, 0x00);  /* MUX 0x24, GPIOA */
//        mux_Tx(0x24, 0x13, 0x00);  /* MUX 0x24, GPIOB */
        light_flash_pwm(c_error_led_pin, &t_error_light, &f_error_light_state, c_error_light_flash, x_dimmer_setting);
        f_serial_state = false;
      }
      else { /* serial hasn't timed out, proceed as normal */
        f_serial_state = true;

        /* turn off the error light, if it was flashing on when serial started it stays on! */
        digitalWrite(c_error_led_pin, LOW);

        /* set the status byte */
        x_databuffer[0] = B00000011; /* bit 1 is true (alive) and bit 2 is true (powered) */
        /* read all the inputs into the databuffer */
        read_inputs(&x_databuffer[1]);

        /* write the outputs to the lights  */
        if (f_data_received) {
          write_outputs(x_inputbuffer, x_databuffer);
          f_data_received = FALSE;
        }
      }
      /* manage dimmer controls */
//      light_dim_ctl(c_dimmer_pwm_pin, f_serial_state, x_dimmer_setting, 0);
//      light_dim_ctl(c_ap_power_pin, f_serial_state, x_dimmer_setting, 0);
//      light_dim_ctl(c_ap_dimmer_pin, f_ap_power_state, x_dimmer_setting, 0);
//      light_dim_ctl(c_ap_reset_pin, f_ap_power_state, x_dimmer_setting, 0);

      /* measure the processing time, signal if an overun occurs. add actual frame time to data buffer */
      t_frame_actual = millis() - t_current_frame;
      x_databuffer[27] = t_frame_actual;

      if (t_frame_actual >= c_frame_time_target) {
        digitalWrite(c_overrun_led_pin, HIGH);
        #ifdef DEBUG
        Serial.println(t_frame_actual);
        #endif
      }
      else {
        digitalWrite(c_overrun_led_pin, LOW);
      }

      /* add the fan speed data to the buffer */
      x_databuffer[28] = 0x99;

      /* if data was requested, send data back */
      if (f_data_requested) {
        Serial.write(x_databuffer, sizeof(x_databuffer));
        f_data_requested = FALSE;
      }
  } /* end of 'if frame time reached' condition */
}

int read_inputs(byte buff[]) {
  /* this function reads in all digital inputs and places them in the data buffer */
  /* first clear the data buffer in the area we will do bit setting */
  for (i = 0; i < 5; i++) {
    buff[i] = 0;
  }

  /* read and map in the direct digital IO pins */
  for (i = c_first_input_pin1; i <= c_last_input_pin1; i++) {
    bitWrite(buff[0], (i - c_first_input_pin1) % 8, !digitalRead(i));
  }

  /* now read the digital ins from each MUX bank.
      note that they already come as bytes so they can be copied straight in.
  */
  mux_Rx(0x20, 0x12, 1, &buff[5]);
  mux_Rx(0x20, 0x13, 1, &buff[6]);
//  mux_Rx(0x21, 0x12, 1, &buff[7]);
//  mux_Rx(0x21, 0x13, 1, &buff[8]);
//  mux_Rx(0x22, 0x13, 1, &buff[9]);
//  mux_Rx(0x23, 0x13, 1, &buff[10]);
//  mux_Rx(0x24, 0x13, 1, &buff[11]);
//  mux_Rx(0x25, 0x12, 1, &buff[12]);
//  mux_Rx(0x25, 0x13, 1, &buff[13]);
//  mux_Rx(0x26, 0x12, 1, &buff[14]);
//  mux_Rx(0x26, 0x13, 1, &buff[15]);

  /* read the analog inputs and map to a byte */   
//  buff[16] = map(analogRead(A0), 0, 1023, 0, 255); /* Voltage sensor */
    buff[17] = map(GetTemp(), 0, 1023, 0, 255); /* Temperature Sensor */
//  buff[18] = map(analogRead(A2), 0, 1023, 255, 2); /* Dimmer - REVERSED - set a minimum to avoid no lights */
  selectAMuxPin(1);
  buff[19] = map(analogRead(zInput), 0, 1023, 0, 255); /* Rotation X */
  selectAMuxPin(2);
  buff[20] = map(analogRead(zInput), 0, 1023, 0, 255); /* Rotation Y */
  selectAMuxPin(0);
  buff[21] = map(analogRead(zInput), 0, 1023, 0, 255); /* Rotation Z */
//  buff[22] = map(analogRead(A6), 0, 1023, 255, 0); /* Translation X - REVERSED */
//  buff[23] = map(analogRead(A7), 0, 1023, 0, 255); /* Translation Y */
//  buff[24] = map(analogRead(A8), 0, 1023, 0, 255); /* Translation Z */
  selectAMuxPin(3);
  buff[25] = map(analogRead(zInput), 0, 1023, 0, 255); /* Throttle */
  return 0;
}

int write_outputs(byte inputs[], byte outputs[]) {
  byte temp = 0;
  /* start by mapping in the input data, then overwrite with locally driven lights from the output buffer*/
  temp = inputs[1]; /*shortcut to map in bits 0-3 */
//  bitWrite(temp, 4, bitRead(outputs[9], 7)); /* staging armed */
//  bitWrite(temp, 5, (bitRead(outputs[9], 3) || bitRead(outputs[9], 4) || bitRead(outputs[9], 5) || bitRead(outputs[9], 6))); /* throttle armed */
//  bitWrite(temp, 6, (bitRead(outputs[9], 4) || bitRead(outputs[9], 5) || bitRead(outputs[9], 6))); /* throttle limited */
//  bitWrite(temp, 7, bitRead(outputs[9], 2)); /* SAS Power On */
//  mux_Tx(0x23, 0x12, temp);  /* MUX 0x23, GPIOA */

  temp = 0; /* we are not receiving anything here */
  bitWrite(temp, 0, bitRead(outputs[7], 6)); /* Controls Fine */
//  mux_Tx(0x23, 0x13, temp);  /* MUX 0x23, GPIOB */

  temp = inputs[2]; /* shortcut to map in bits 0-3 and 5. Bit 4 will be overwritten later*/

  /* output 5 is the gear indicator. It should be on if gear is down (inputs[2] bit 5 is true), off
      if down(inputs[2] bit 4 is true) and flashing otherwise
  */
//  if (!(bitRead(inputs[2], 4) || bitRead(inputs[2], 5))) {
//    t_gear_flash_timer += t_frame_time;
//    bitWrite(temp, 5, int(t_gear_flash_timer / c_gear_light_flash) % 2);
//  }
//  else {
//    t_gear_flash_timer = 0;
//  }
//  bitWrite(temp, 4, bitRead(outputs[11], 3)); /* NWS armed */
//  bitWrite(temp, 6, (bitRead(outputs[11], 5) || bitRead(outputs[11], 6))); /* Brakes */
//  bitWrite(temp, 7, bitRead(outputs[11], 1)); /* Lights */
//  mux_Tx(0x24, 0x12, temp);  /* MUX 0x24, GPIOA */

  temp = 0; /* we are not receiving anything here */
  bitWrite(temp, 0, bitRead(outputs[11], 2)); /* Controls Fine */
//  mux_Tx(0x24, 0x13, temp);  /* MUX 0x24, GPIOB */
}

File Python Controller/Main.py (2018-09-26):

from multiprocessing import Process, Queue, Array
from tkinter import Tk
import ctypes
from time import sleep, time
from Settings import *
from GUI import Application

# Define the shared data between the processes
msgQ = Queue(0)
data_array = Array(ctypes.c_ubyte, 50)

if __name__ == '__main__':
    # Create the root window
    root = Tk()
    root.title('KSP Controller')
    root.configure(background = "black")
    root.geometry('{0}x{1}'.format(c_screen_size_x,c_screen_size_y) + c_screen_pos)

    # Instatiate the GUI
    app = Application(root, data_array, msgQ)

    stage_prev = None
    frame_time = time()

    # Loop the window, calling an update then refreshing the window
    while 1:
        if time() > frame_time + 0.250:
            frame_time = time()

            if app.game_connected == False or app.vessel_connected == False:
                app.connect(msgQ)
            elif app.conn.krpc.current_game_scene == app.conn.krpc.current_game_scene.flight:
                if app.vessel.control.current_stage is not stage_prev:
                    app.update_streams()
                stage_prev = app.vessel.control.current_stage
                app.update(data_array, msgQ)

            root.update()
            root.update_idletasks()

            frame_delta = time() - frame_time
            if frame_delta > 0.25:
                print ('{0:0f}ms'.format(frame_delta*1000))

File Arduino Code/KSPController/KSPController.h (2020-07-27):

/* Definitions */
#define TRUE 1
#define FALSE 0
//#define DEBUG               /* This flag will enable debug code */

/* Pin Assignments */
/* Analog Multiplex Vars */
const int p.selectPins[3] = {15, 16, 14}; // S0~2, S1~3, S2~4
const int p.zinput = A0; 
/* I2C */
const int p.scl = 4;
const int p.sda = 3;
/* PWM output */
const int p.Dim = 11;
const int p.bDim = 10;
const int p.motc = 9;
const int p.powerled = 5;
const int p.errled = A7;
/* Misc */
const int p.qsav = 13;
const int p.stagearm = p.Qsav; /*Qsav on schematic, arming in practice*/
const int p.qload = 12;
const int p.abortarm = p.Qload;

/* Pin Ranges */
const int outputs[10] = {5,A7,9,10,11,12,13,14,15,16};
const int inputs[8] = {A0,A1,A2,A3,A4,A5,A6,A8};

/* Variables */
byte x_databuffer[40];                  /* byte buffer for managing outputs */
byte x_inputbuffer[3];                  /* byte bugger for managing inputs */
//char s_ap_text1[41];                    /* AP panel message text line 1*/
//char s_ap_text2[41];                    /* AP panel message text line 2*/
//char s_ap_text_cons[3][13];             /* AP text constructor strings */
int f_data_received = 0;                /* data received flag */
int f_data_requested = 0;               /* data requested flag */
int i;                                  /* general loop counter */
int j;                                  /* general loop counter */
int n_mux_chips_detected = 0;           /* number of MUX chips detected in the IBIT */
int f_critical_error = 0;               /* critical error detected flag */
int f_power_on_first_pass = 1;          /* first pass flag when main power is turned on */
int x_dimmer_setting = 0;               /* dimmer setting */
int f_power_light_state = 0;            /* power light flash state */
int f_error_light_state = 0;            /* error light flash state */
int f_serial_state = 0;                 /* state of serial comm */

unsigned long t_power_light = 0;        /* timer for power light flashing calculation */
unsigned long t_overun_light = 0;       /* timer for overun light hold calculation */
unsigned long t_current_frame = 0;      /* current frame start time */
unsigned long t_frame_time = 0;         /* the simulation time for the current frame */
unsigned long t_last_frame = 0;         /* time since last frame */
unsigned long t_frame_actual = 0;       /* actual time it took to process the current frame */
unsigned long t_run_time = 0;           /* time since main power on */
unsigned long t_power_on = 0;           /* time when main power came on */
//unsigned long t_gear_flash_timer = 0;   /* timer for gear light flash calculation */
unsigned long t_last_serial_time = 0;   /* time since last serial data arrived */
unsigned long t_error_light = 100;        /* timer for error light flashing */

/* constants */
//const int c_power_light_flash = 1000;   /* power light flash rate [ms] */
//const int c_frame_time_target = 3;     /* target frame time [ms]*/
//const int c_gear_light_flash = 100;     /* gear light flash rate [ms]*/
const int c_light_bit_time = 1000;      /* time to delay to allow light BIT test to be seen [ms]*/
//const int c_serial_timeout = 5000;      /* serial timeout [ms]*/
//const int c_error_light_flash = 250;    /* no data flash rate for error light [ms]*/
  const byte add.matrix=0x20;      // I2C Address of matrix's MCP23017 chip
  const byte add.ledc=0x21; // I2C Address of LED Control MCP23017
  const byte IODIRA=0x00; // Register address of I/O configuration A
  const byte IODIRB=0x01; // Register address of I/O configuration B
  const byte GPIOA=0x12; // Register Address of Port A
  const byte GPIOB=0x13; // Register Address of Port B
  const byte qrows[8] = {0b11111110,0b11111101,0b11111011,0b11110111,0b11101111,0b11011111,0b10111111,0b01111111};

/* function prototypes*/
int read_inputs(byte buff[]);
int write_outputs(byte inputs[], byte outputs[]);

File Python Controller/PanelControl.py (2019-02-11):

import sys
import serial
import krpc
import time
import operator

import Settings
from Utilities import is_set, norm
from OutputFunctions import output_mapping
from InputFunctions import flight_control_inputs #SAS_inputs, camera_inputs
#from LandingGuidance import ldg_guidance_draw, ldg_guidance_clear
from CNIA import cnia
#from Autopilot import Autopilot

def testmq(mQ):
    mQ.put((0,'test message'))

def panel_control(data_array, mQ):
    sys.stdout = open('panelcontrolout.txt', 'w')
    sys.stderr = open('panelcontrolerror.txt', 'w')
    n_program_state = 1
    t_quickload_timer = 0
    t_frame_start_time = time.time()
    BA_input_buffer = bytearray()
    f_first_pass = 1
    x_trim = [0, 0, 0]
    throttle_inhib = False
    spd_err = 0
    spd_err_p = 0

    while 1:
        if time.time() - t_frame_start_time >= Settings.c_loop_frame_rate:
            # record the start of the processing so we can get timing data
            t_frame_start_time = time.time()

            # STATE = PANEL CONN - Connect to the panel
            if n_program_state == 1:
                mQ.put((0, 'Connecting to the panel....'))
                try:
                    ser = serial.Serial('./COM3', 115200, timeout=0.1)
                    mQ.put((0, 'Connected to the panel'))
                    time.sleep(5)  # serial needs a little bit of time to initialise, otherwise later code - esp CNIA fails
                    n_program_state = 2
                except serial.serialutil.SerialException:
                    mQ.put((1, 'Could not connect to the panel'))
                    time.sleep(5)  # to avoid spamming the message queue
                    pass

            # STATE = GAME CONN - Connect to the KRPC Server
            if n_program_state == 2:
                mQ.put((0, 'Connecting to the game server....'))
                try:
                    conn = krpc.connect(name='Game Controller')
                    mQ.put((0, 'Connected to the game server'))
                    n_program_state = 3
                except ConnectionRefusedError:
                    mQ.put((1, 'Could not connect to the game server'))
                    pass

            # STATE = LINKING - Link to the active Vessel
            if n_program_state == 3 and conn.krpc.current_game_scene == conn.krpc.current_game_scene.flight:
                mQ.put((0, 'Connecting to the vessel....'))
                try:
                    vessel = conn.space_center.active_vessel
                    mQ.put((0, 'Linked to ' + vessel.name))
                    n_program_state = 4
                except krpc.client.RPCError:
                    mQ.put((1, 'Could not connect to a vessel'))
                    pass

            # STATE = Perform CNIA
            if n_program_state == 4:
                mQ.put((0, 'Starting CNIA...'))
                try:
                    cnia(ser, conn, vessel,mQ)
                    mQ.put((0, 'CNIA Complete'))
                    n_program_state = 5
                except TimeoutError as err:
                    mQ.put((0, ' '.join(err.args)))
                    time.sleep(5)
                    pass


            # STATE = Streams and objects- setup data input streams and reused objects
            if n_program_state == 5:
                # Get SAS status
                mQ.put((0, 'Begin stream setup'))
                sas_stream = [conn.add_stream(getattr, vessel.control, 'sas')]
                mQ.put((0, 'Stream setup complete'))
                n_program_state = 6

            # STATE = RUNNING
            if n_program_state == 6:
                try:  # catch RPC errors as they generally result from a scene change. Make more specific KRPC issue 256
                    # Send data to the arduino request it to process inputs  - command byte = 0x00
                    BA_output_buffer = bytearray([0x00, 0x00, 0x00])
                    ser.write(BA_output_buffer)

                    # Now while the Arduino is busy with inputs we processes the outputs - command byte = 0x01
                    #BA_output_buffer = bytearray([0x01, 0x00, 0x00])
                    #output_mapping(BA_output_buffer, conn, sas_stream)

                    # Make sure the Arduino has responded
                    while ser.in_waiting != 40:
                        pass

                    # read back the data from the arduino
                    BA_input_buffer_prev = BA_input_buffer
                    BA_input_buffer = ser.read(40)

                    # Now send the output date we calculated earlier
                    # ser.write(BA_output_buffer)

                    if f_first_pass:  # On the first pass copy the data in to avoid an error.
                        BA_input_buffer_prev = BA_input_buffer
                        f_first_pass = 0
                    
                    # Check the status of the Arduino and make the controls work
                    #mQ.put((0,'input buffer is ' + BA_input_buffer[0]))
                    if BA_input_buffer[0] == 3:  # status of 00000011 is fully powered
                        # SAS
                        #SAS_inputs(BA_input_buffer, BA_input_buffer_prev, vessel, mQ)
                        # Flight Control (currently just throttle)
                        try:
                            sas_overide = flight_control_inputs(BA_input_buffer, vessel, x_trim, throttle_inhib, mQ)
                        except Exception as e:
                            mQ.put((1,'flight control error'))
                            mQ.put((1,repr(e)))
                        # put all the data onto the shared array for use by the GUI
                        #mQ.put((0,'ran flight control'))
                        for i in range(len(BA_input_buffer)):
                            data_array[i] = BA_input_buffer[i]
                        #mQ.put((0,'out of loop'))

                except krpc.client.RPCError:
                    n_program_state = 3
                    mQ.put((1, 'Main Loop Error'))

            # Check for Overuns and send a warning.
            if (time.time() - t_frame_start_time) > Settings.c_loop_frame_rate * 1.1:
                mQ.put((1, 'OVERUN - ' + str(int((time.time() - t_frame_start_time) * 1000)) + 'ms'))

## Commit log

2016-08-02 Initial Upload
    Initial upload of all SW and Docs done to date
    [KSP Controller Design Data.xlsx, Panel Schematics.dsn]
2016-08-05 Fixed power off and serial out issues
    [KSP Controller Design Data.xlsx]
2016-08-05 Updated Documentation and Schematics
    Commenced design doc and added I2C Pull Up resistors.
    [Panel Schematics.dsn]
2016-08-07 Update do design notes
    [KSP Controller Design Data.xlsx]
2016-08-07 Various GUI Updates
    Started adding data to GUI Tab 2, which required more data from the
    Arduino
    [KSP Controller Design Data.xlsx]
2016-08-15 GUI Updates
    Adding a lot of GUI features plus
    - tolerance on CNIA for throttle
    - changed the sub process start to allow run without panel and reconnect
    - lots of python code cleanup
    [CNIA.py, GUI.py, Main.py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]
2016-08-15 SAS Overide
    Disable SAS when the pitch controller is in use. SAS tries to filter out
    the inputs and then overcompensates when you release. On release of the
    controller SAS re-engages automatically
2016-08-15 Added more GUI stuff
    Landing is a copy of launch for now, and added Rondezvous data which is
    wobly as orbits are unstable. Also slowed down the GUI.
    [GUI.py, Main.py, PanelControl.py]
2016-08-20 Documentation Updates
    Documented Arduino Code and added electrical grounding descriptions.
    Alse fixed a type in an arduino file but it has no real effect.
    [KSP Controller Design Data.xlsx]
2016-10-02 GUI Update
    Improved plots with switching built in, and add frame timing to GUI for
    consistent behaviour. A lot of performance updates.
2016-10-02 Autopilot Panel
    Major update to integrate autopilot panel. Note not all drawings and
    docs are updated yet! And the Python side is not ready for it. (should
    have done this as a branch!)
    [KSP Controller Design Data.xlsx]
2016-10-13 AP Panel Improvements
    Added a fastmode to value setting if you hold the button down, and setup
    ability for selected modes to wrap values, e.g. heading
2016-10-13 Documentation Updates
    Updated data file for new data transfers for AP, and updated schematics
    to show AP panel
    [KSP Controller Design Data.xlsx, Panel Schematics.dsn]
2016-10-13 Autopilot and KRPC 3.6
    Added AP interface to Arduino, updated GUI to show AP data and button
    maint data. Setup first basic AP code (WIP). Updated for KRPC 3.6.
2018-09-26 commented or removed unused, started CNIA exception handling
    [KSP Controller Design Data.xlsx, Panel Schematics.dsn]
2018-10-01 Added CNIA timeout error
    [PartList.xlsx]
2019-02-11 Lots of revisions
    [3buttonpanel.kicad_pcb, 3buttonpanel.sch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]
2019-10-11 Uploaded test projects and prototypes to date
    [3buttonpanel.kicad_pcb, 3buttonpanel.sch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]
2020-02-17 V2 Panels. Matrix Input Test Sketch
    [7Button-B_Cu.gbr, 7Button-B_Mask.gbr, 7Button-B_Paste.gbr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]
2020-03-09 Corrected Unavailable 74HC4051 footprint on Shield Board
    [Shield v.2-B_Cu.gbr, Shield v.2-B_Fab.gbr, Shield v.2-B_Mask.gbr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]
2020-07-04 Catch Up
    [2mmcross.dxf, AcrylicCutTest1.dxf, AcrylicCutTest2.dxf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]
